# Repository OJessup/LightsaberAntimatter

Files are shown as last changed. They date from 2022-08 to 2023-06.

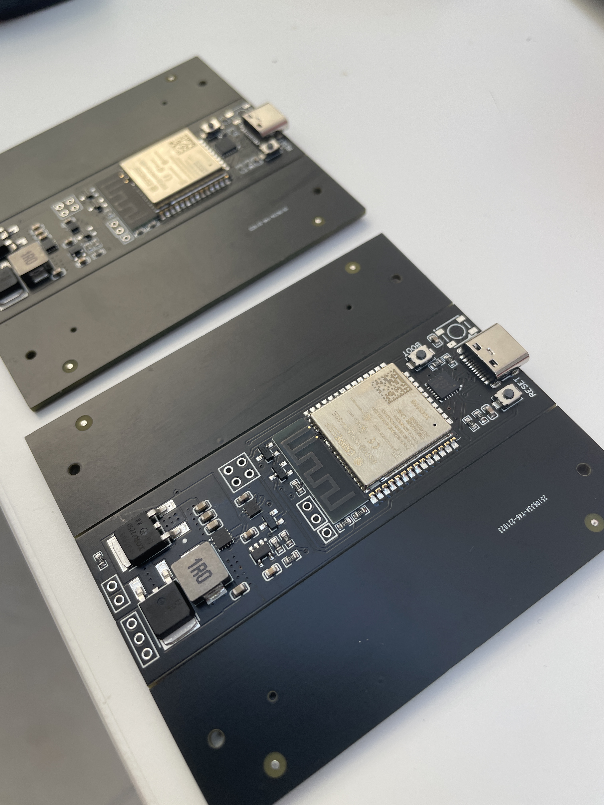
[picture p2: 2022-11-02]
ProgressDump/IMG_3393.JPG

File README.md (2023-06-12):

# LightsaberAntimatter

The LightsaberAntimatter is the third prototype of my special-fx lightsaber design.

The saber consists of two circuit boards, one with an esp-32 that controls leds that run the length of the blade, gathers readings from a gyroscope, manages a single cell battery, communicates with an iphone via bluetooth, and gathers readings from 4 VL53L5CX ToF sensors located on the second circuit board. These ToF sensors are used to detect if and where the lightsaber is hit along the blade, allowing the ability for the lightsaber to flash at a particular spot along the blade, bringing greater interactivity to it's environment and reducing the vfx needed in film production.

The hilt is a custom design, gathering inspiration from the starkiller lightsaber hilt.

Schematics for the PCBS are found in the schematics folder as well as the circuitboards folder and their fabrication files are found in the PCBA file. The DocsAndDiagrams folder is a simplified block diagram of the main circuit board, though it is outdated. The main code of the board and iphone are found in Code/StableSoftware. The .step files and technical drawings for the components of the lightsaber can be found in the CAD file.


IMG_4648 (1)

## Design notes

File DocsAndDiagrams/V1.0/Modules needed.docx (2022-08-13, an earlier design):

Modules needed:

- Control board
- IMU
- DC-DC boost converter
- SR-latch
- I2S CODEC
- Amplifier & speaker
- 1 cell lipo manager
- USB-C
- Main power mosfet & led power mosfet
- ESP8266
- Capacitive touch sensor
- Current sensor

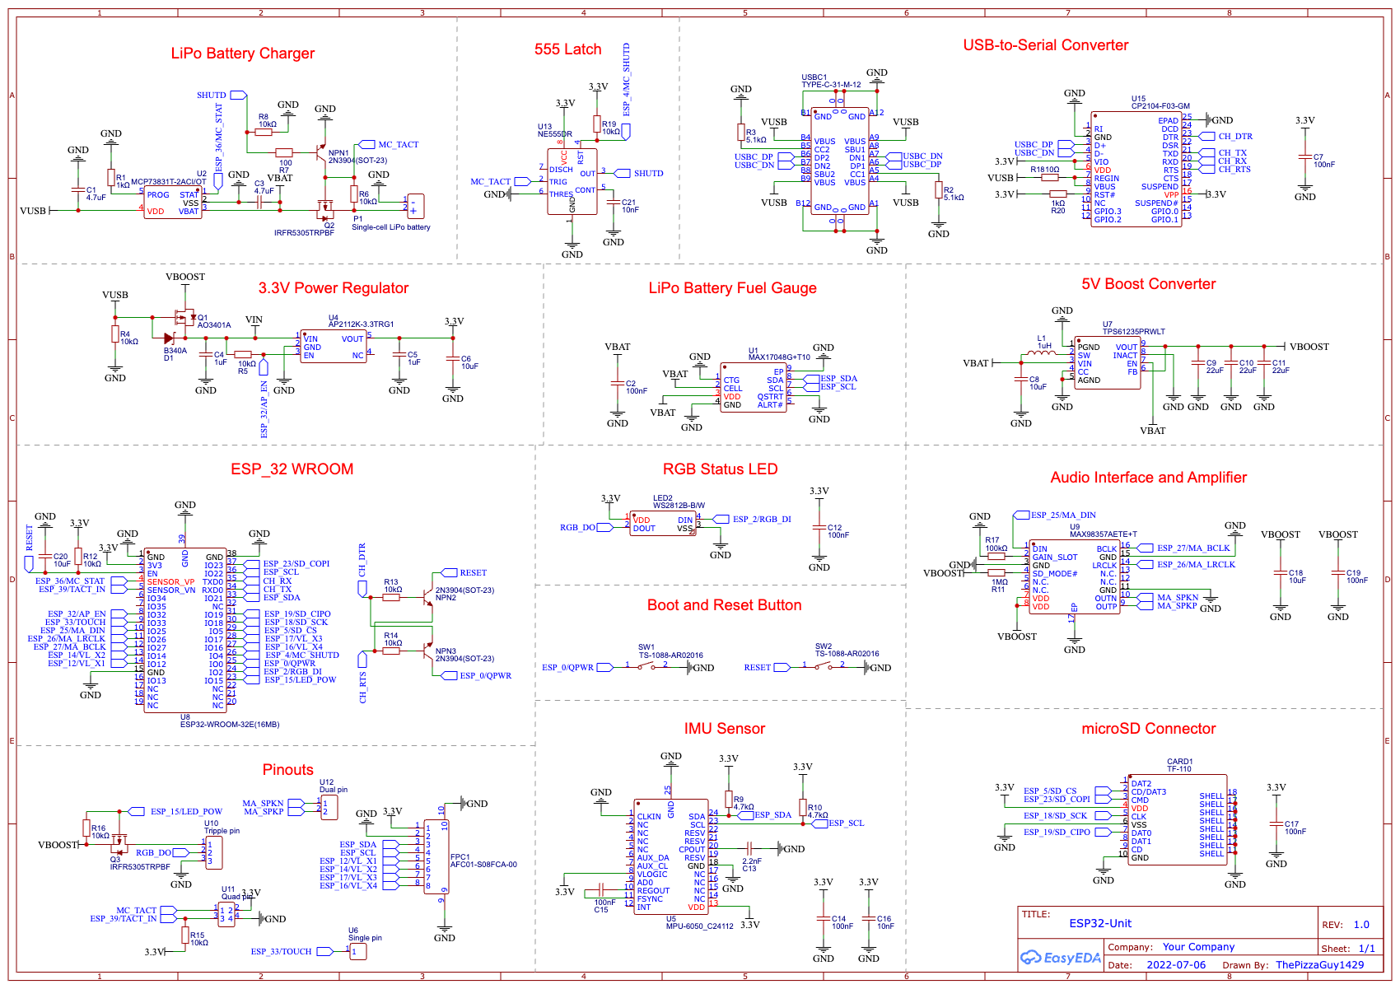
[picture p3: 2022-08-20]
Circuits/MainPCB/Schematic_Lightsaber [Anti-matter] ESP32-Unit_2022-08-20.png

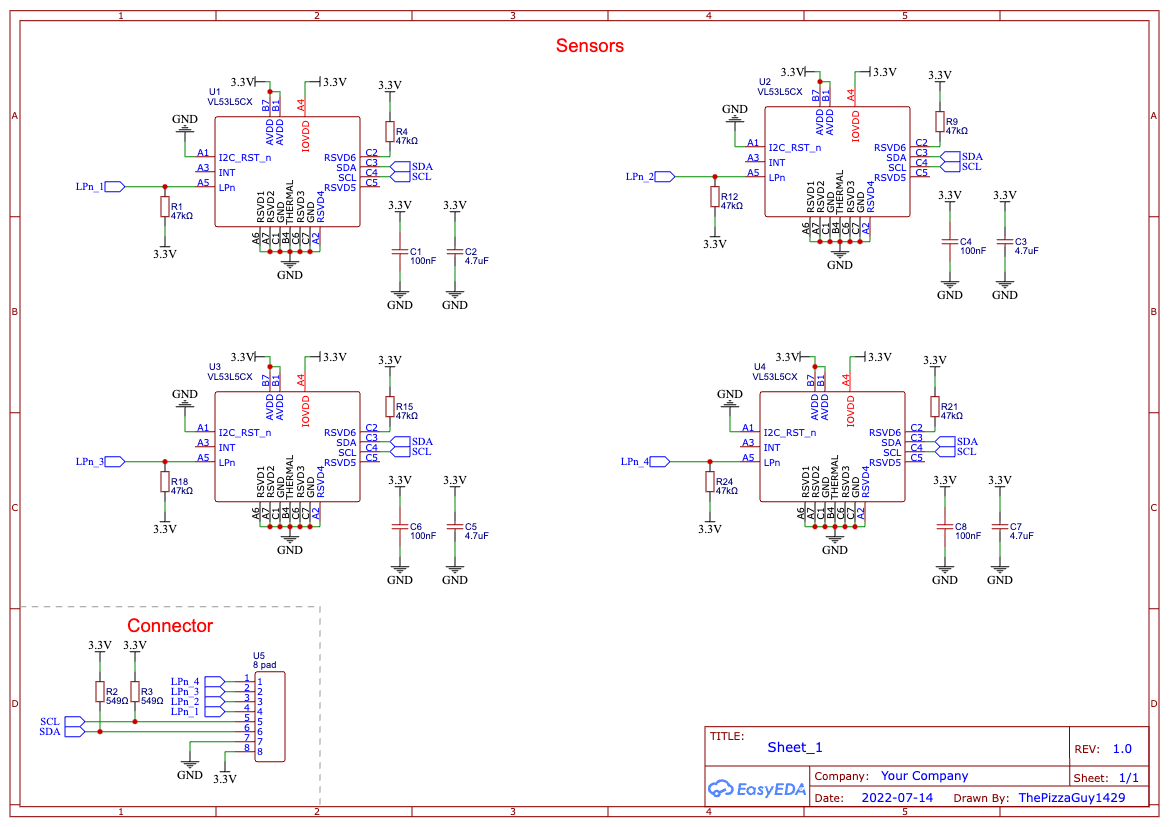
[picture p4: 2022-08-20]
Circuits/SensorPCB/Schematic_Lightsaber [Anti-matter] VL53L5CX_2022-08-20.png

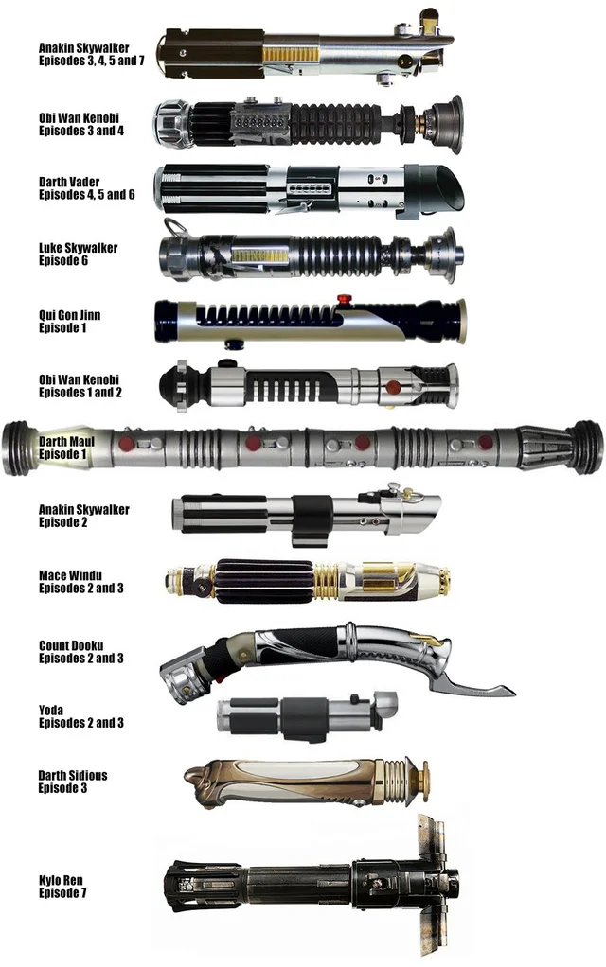
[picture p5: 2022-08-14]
Inspiration/Existing lightsabers.jpeg

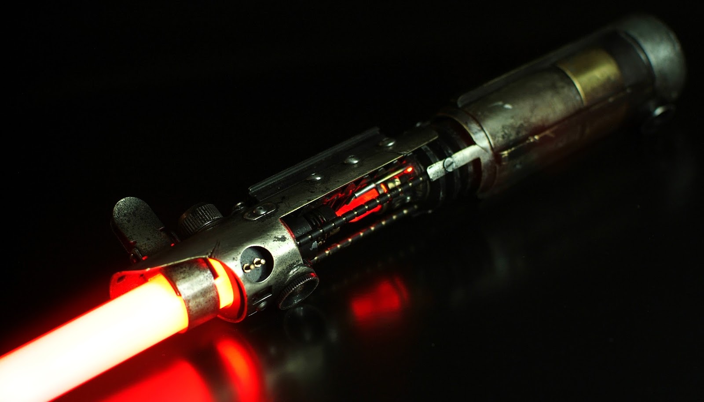
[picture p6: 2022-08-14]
Inspiration/starkiller 2.jpeg

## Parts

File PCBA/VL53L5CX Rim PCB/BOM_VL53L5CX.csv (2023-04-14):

ID | Name | Designator | Footprint | Quantity | Manufacturer Part | Manufacturer | Supplier | Supplier Part | Price
1 | 100nF | C1,C4,C6,C8 | C0603 | 4 | CC0603KRX7R9BB104 | YAGEO | LCSC | C14663
2 | 4.7uF | C2,C3,C5,C7 | C0603 | 4 | CL10A475KO8NNNC | SAMSUNG | LCSC | C19666 | 0.002
3 | 47kΩ | R1,R4,R9,R12,R15,R18,R21,R24 | R0603 | 8 | 0603WAF4702T5E | UniOhm | LCSC | C25819
4 | VL53L5CX | U1,U2,U3,U4 | VL53L5CX | 4 | VL53L5CXV0GC/1 | ST | Mouser | 511-VL53L5CXV0GC/1

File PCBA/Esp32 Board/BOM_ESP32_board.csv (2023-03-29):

ID | Name | Designator | Footprint | Quantity | Manufacturer Part | Manufacturer | Supplier | Supplier Part | Price
1 | MCP73832T-2ACI/OT | U2 | SOT-23-5_L3.0-W1.7-P0.95-LS2.8-BR | 1 | MCP73832T-2ACI/OT | MICROCHIP(美国微芯) | LCSC | C38066 | 0.149
2 | VL53L5CXMainBoard | J1 | VL53L5CXMAINBOARD | 1
3 | 100nF | C11,C1,C14,C15 | C0603 | 4 | CC0603KRX7R9BB104 | YAGEO(国巨) | LCSC | C14663
4 | 10uF | C10,C8,C21,C2 | C0603 | 4 | CL10A106MA8NRNC | SAMSUNG | LCSC | C96446 | 0.004
5 | 2.2nF | C16 | C0603 | 1 | 0603B222K500NT | FH | LCSC | C1604
6 | 100nF | C17,C18,C20 | C0603 | 3 | CC0603KRX7R9BB104 | YAGEO | LCSC | C14663
7 | 10nF | C19,C23 | C0603 | 2 | 0603B103K500NT | FH | LCSC | C57112
8 | TF-110 | CARD1 | TF-SMD_TF-110 | 1 | TF-110 | XUNPU | LCSC | C266613 | 0.038
9 | 2N3904(SOT-23) | NPN1,NPN2 | SOT-23-3_L2.9-W1.3-P1.90-LS2.4-TR | 2 | 2n3904S-RTK/PS | KEC | LCSC | C18536 | 0.002
10 | 100kΩ | R5 | R0603 | 1 | 0603WAF1003T5E | UniOhm | LCSC | C25803
11 | 1MΩ | R7 | R0603 | 1 | 0603WAF1004T5E | UniOhm | LCSC | C22935
12 | 10kΩ | R11,R12,R13,R6 | R0603 | 4 | RMC060310K1%N | Tyohm | LCSC | C269701 | 0.001
13 | MPU-6050_C24112 | U6 | QFN-24_L4.0-W4.0-P0.50-BL-EP2.7 | 1 | MPU-6050 | InvenSense | LCSC | C24112 | 1.409
14 | PCA9536D_C129522 | U7 | SOIC-8_L4.9-W3.9-P1.27-LS6.0-BL | 1 | PCA9536D | NXP(恩智浦) | LCSC | C129522 | 0.212
15 | MAX98357AETE+T | U9 | TQFN-16_L3.0-W3.0-P0.50-BL-EP1.5 | 1 | MAX98357AETE+T | MAXIM(美信) | LCSC | C910544 | 0.139
16 | 4.7uF | C12,C13 | C0603 | 2 | CL10A475KO8NNNC | SAMSUNG | LCSC | C19666 | 0.002
17 | 1kΩ | R10 | R0603 | 1 | 0603WAF1001T5E | UniOhm | LCSC | C21190
18 | 100uF | C4,C5,C9,C22,C27 | C1206 | 5 | GRM31CR61A107ME05L | muRata(村田) | LCSC | C312983 | 0.033
19 | 1uH | L1 | IND-SMD_L7.1-W6.5-P5.60 | 1 | SPM6530T-1R0M120 | TDK | LCSC | C87572 | 0.03
20 | 5V | J4 | HDR-M-2.54_1X2 | 1 |  |  | LCSC | C124375 | 0.004
21 | LEDout | J7 | HDR-M-2.54_1X1 | 1 |  |  | LCSC | C81276 | 0.001
22 | TS-1088-AR02016 | BOOT,RST | SW-SMD_L4.0-W2.9-LS5.0 | 2 | TS-1088-AR02016 | XUNPU | LCSC | C720477 | 0.008
23 | 22uF | C3 | C0603 | 1 | CL10A226MQ8NRNC | SAMSUNG(三星) | LCSC | C59461 | 0.001
24 | 10pF | C25 | C0603 | 1 | CL10C100JB8NNNC | SAMSUNG(三星) | LCSC | C1634 | 0.001
25 | 1uF | C6,C7,C24,C26 | C0603 | 4 | CL10A105KB8NNNC | SAMSUNG | LCSC | C15849 | 0.001
26 | B5819WS_C169530 | D1,D2,D3 | SOD-323F_L2.0-W1.6-LS2.5-RD | 3 | B5819WS | 晶导微电子 | LCSC | C169530 | 0.003
27 | SPEAKER | J2 | HDR-M-2.54_1X2 | 1 |  |  | LCSC | C124375 | 0.004
28 | BUTTON | J6 | HDR-M-2.54_1X2 | 1 |  |  | LCSC | C124375 | 0.004
29 | TOUCH | J3 | HDR-M-2.54_1X1 | 1 |  |  | LCSC | C81276 | 0.001
30 | Lipo | J5 | HDR-M-2.54_1X4 | 1 |  |  | LCSC | C124378 | 0.007
31 | WS2812B-B/W | LED1 | LED-SMD_4P-L5.0-W5.0-TL_WS2812B-B | 1 | WS2812B-B/T | worldsemi | LCSC | C2761795 | 0.015
32 | AO3401A | Q1 | SOT-23_L2.9-W1.3-P1.90-LS2.4-BR | 1 | AO3401A | AOS | LCSC | C15127 | 0.013
33 | AO3400A | Q3 | SOT-23-3_L2.9-W1.6-P1.90-LS2.8-BR | 1 | AO3400A | AOS | LCSC | C20917 | 0.013
34 | AO4485 | Q4 | SOIC-8_L5.0-W4.0-P1.27-LS6.0-BL | 1 | AO4485 | AOS | LCSC | C51499 | 0.052
35 | 100kΩ | R1,R8,R9 | R0603 | 3 | 0603WAF1003T5E | UNI-ROYAL(厚声) | LCSC | C25803
36 | 1MΩ | R2,R15,R16 | R0603 | 3 | 0603WAF1004T5E | UNI-ROYAL(厚声) | LCSC | C22935
37 | 35.7kΩ | R14 | R0603 | 1 | RTT033572FTP | RALEC(旺诠) | LCSC | C103569
38 | 2.2kΩ | R17,R19 | R0603 | 2 | 0603WAF2201T5E | UNI-ROYAL(厚声) | LCSC | C4190
39 | 332kΩ | R18 | R0603 | 1 | 0603WAF3323T5E | UNI-ROYAL(厚声) | LCSC | C23139
40 | ESP32-WROOM-32E(16MB) | U1 | WIFI-SMD_ESP32-WROOM-32E | 1 | ESP32-WROOM-32E(16MB) | Espressif Systems | LCSC | C701343 | 0.776
41 | XC6210B332MR_C424705 | U3 | SOT-25_L3.0-W1.6-P0.95-LS2.8-BL | 1 | XC6210B332MR | Torex Semicon | LCSC | C424705 | 0.052
42 | MAX17048G+T10 | U4 | DFN-8_L2.0-W2.0-P0.50-BL-EP | 1 | MAX17048G+T10 | MAXIM(美信) | LCSC | C2682616 | 0.241
43 | TPS61236PRWLR | U8 | VQFN-9_L2.5-W2.5-P0.50-TL | 1 | TPS61236PRWLR | TI(德州仪器) | LCSC | C130295 | 0.302
44 | 5.1kΩ | R3,R4 | R0603 | 2 | 0603WAF5101T5E | UniOhm | LCSC | C23186
45 | CP2104-F03-GM | U5 | QFN-24_L4.0-W4.0-P0.50-BL-EP2.7 | 1 | CP2104-F03-GM | SILICON LABS | LCSC | C47742 | 0.299
46 | TYPEC-304-ACP16 | USB1 | USB-C-SMD_TYPE-C-16P-1 | 1 | TYPEC-304-ACP16 | XUNPU(讯普) | LCSC | C2982555 | 0.02

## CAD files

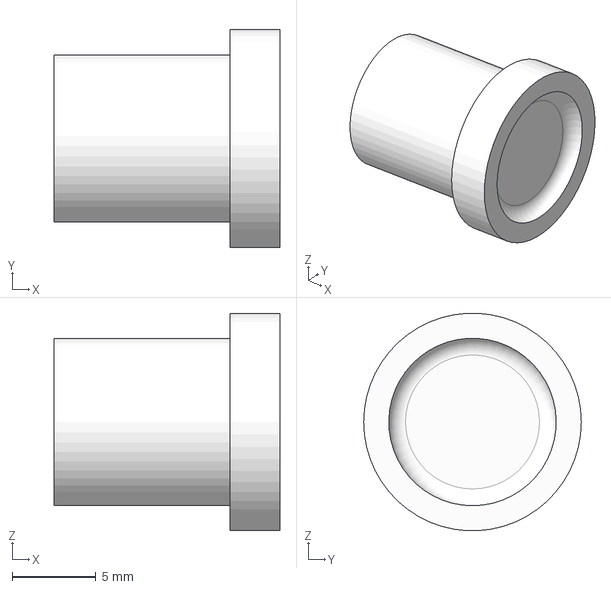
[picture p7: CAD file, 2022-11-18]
CAD/STEP files/SmallKnob-01.step
13.5 x 13.0 x 13.0 mm

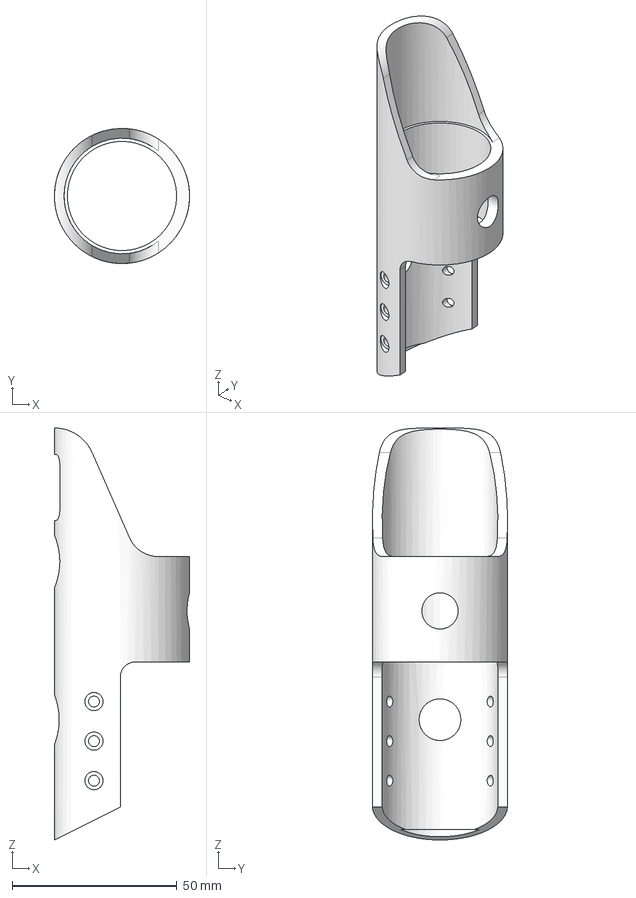
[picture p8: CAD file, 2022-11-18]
CAD/STEP files/EmitterShield-01.step
41.0 x 41.0 x 125.0 mm

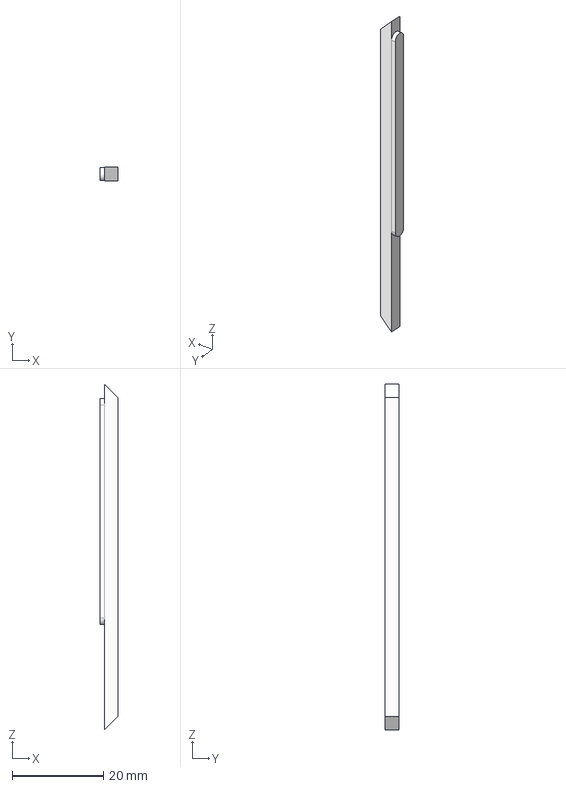
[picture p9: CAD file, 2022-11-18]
CAD/STEP files/GripRailing-01.step
4.00 x 3.00 x 76.0 mm

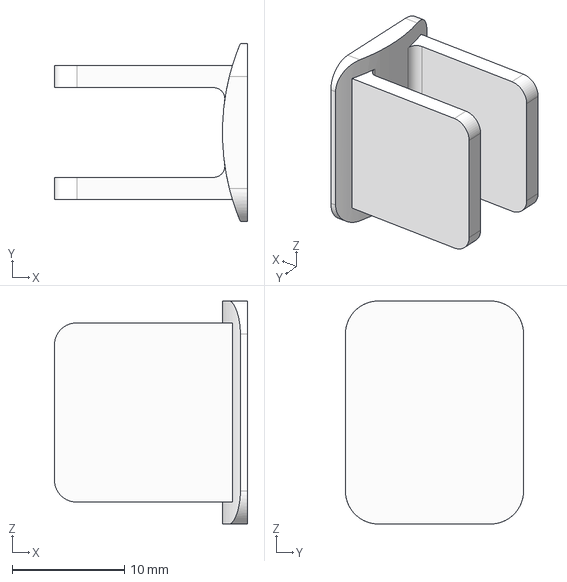
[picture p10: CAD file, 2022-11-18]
CAD/STEP files/Radiator-01.step
17.2 x 15.9 x 19.9 mm

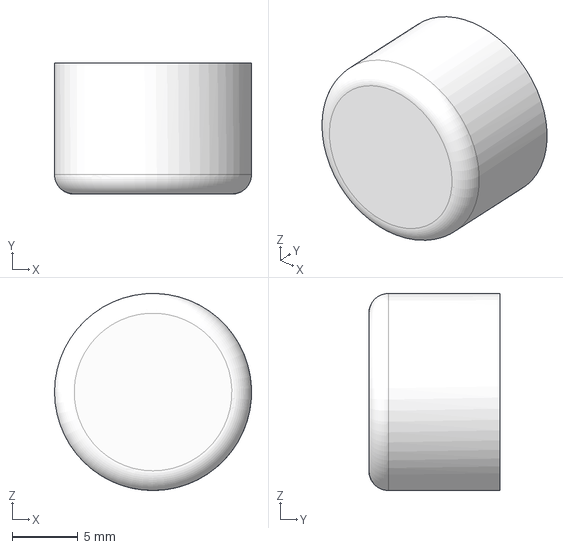
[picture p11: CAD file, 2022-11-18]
CAD/STEP files/LargeKnob-01.step
15.0 x 10.0 x 15.0 mm

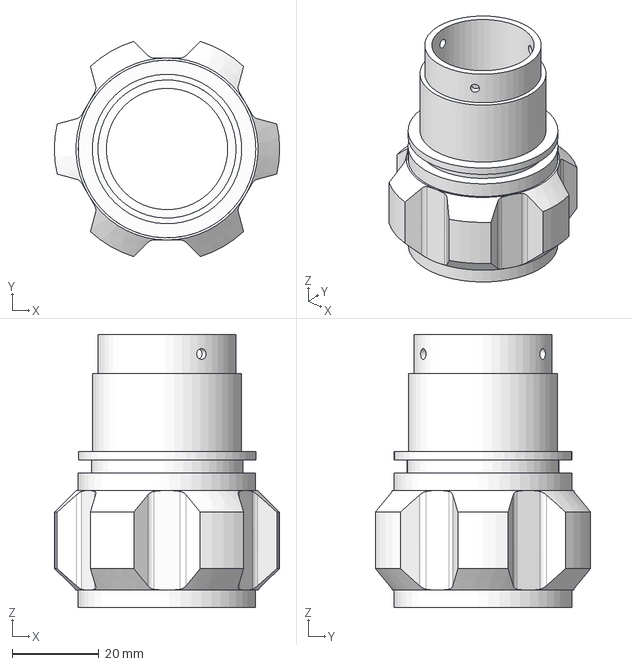
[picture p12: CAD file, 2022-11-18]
CAD/STEP files/GripButt-01.step
52.0 x 49.7 x 63.0 mm

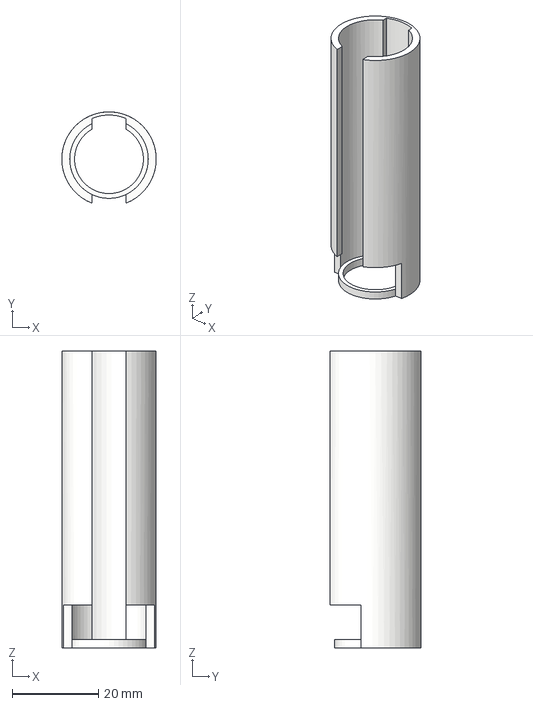
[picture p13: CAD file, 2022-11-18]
CAD/STEP files/BatteryHolder-01.step
21.9 x 21.2 x 69.0 mm

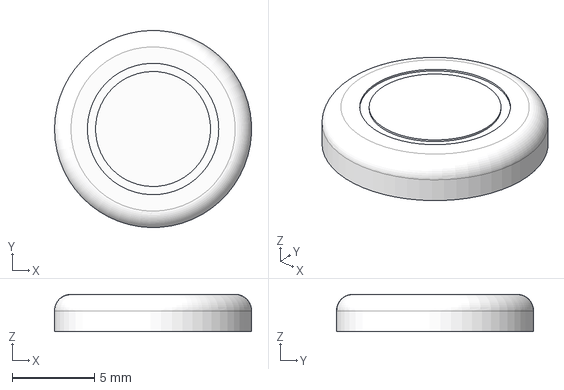
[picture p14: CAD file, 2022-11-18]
CAD/STEP files/Button-01.step
12.0 x 12.0 x 2.27 mm

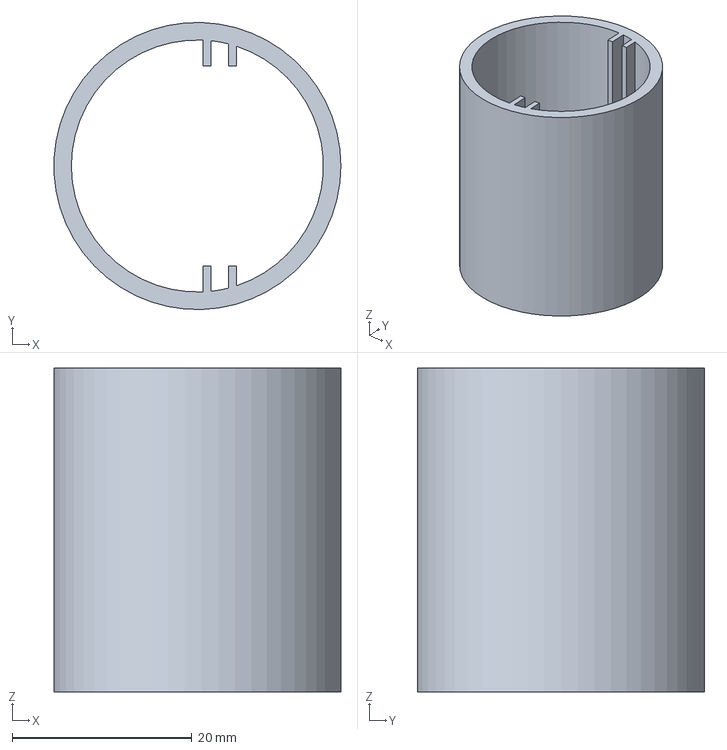
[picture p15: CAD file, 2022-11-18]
CAD/STEP files/PCBSlide-01.step
31.9 x 31.9 x 36.0 mm

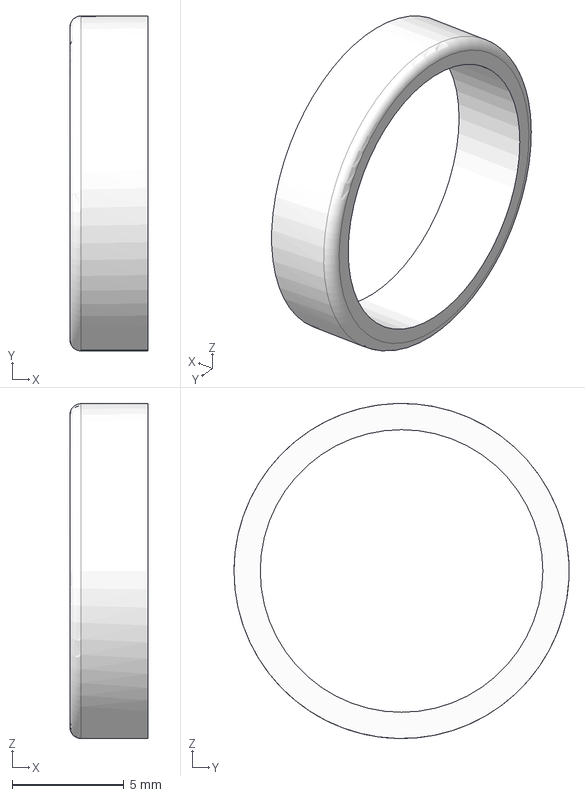
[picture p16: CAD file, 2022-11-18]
CAD/STEP files/ButtonDetail-01.step
3.50 x 15.0 x 15.0 mm

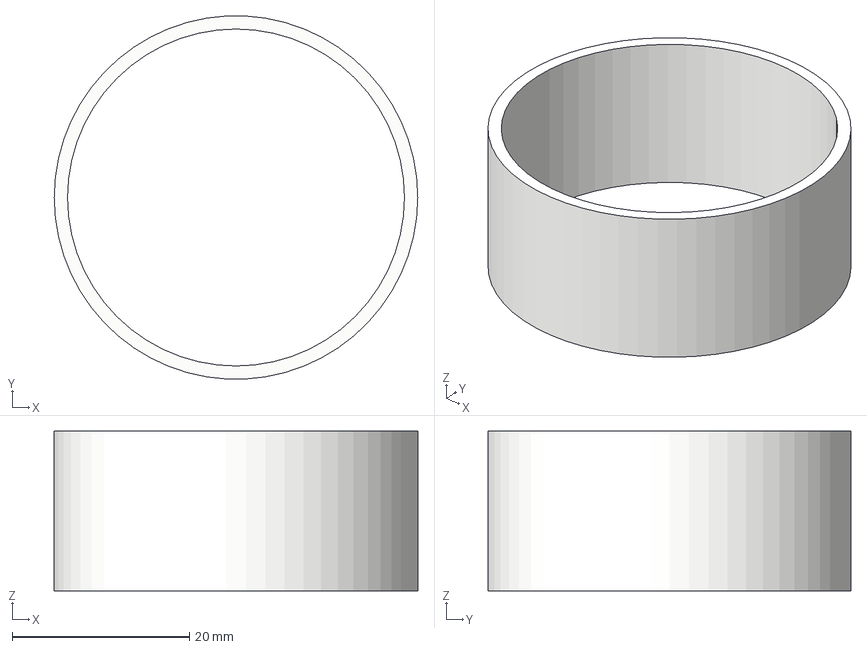
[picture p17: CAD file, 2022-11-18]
CAD/STEP files/PolycarbonateShield-01.step
41.0 x 40.9 x 18.0 mm

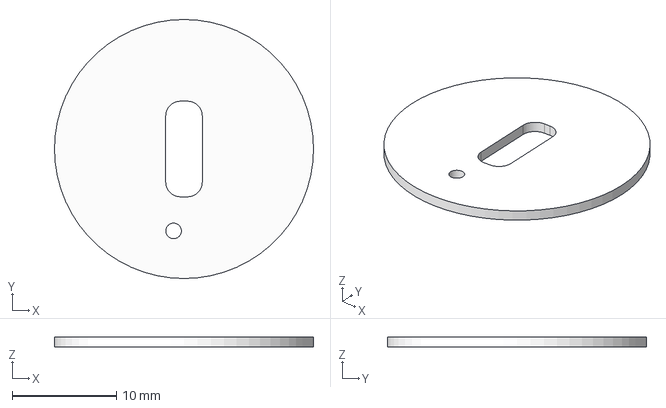
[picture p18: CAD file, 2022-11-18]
CAD/STEP files/InnerPlate-01.step
24.9 x 24.9 x 1.00 mm

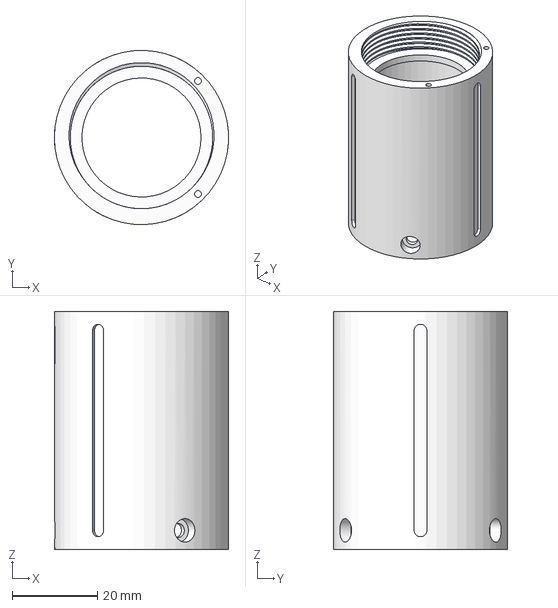
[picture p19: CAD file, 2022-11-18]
CAD/STEP files/GripShield-01.step
41.0 x 41.0 x 56.0 mm

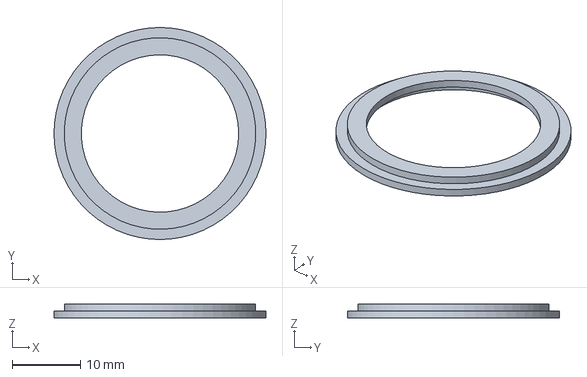
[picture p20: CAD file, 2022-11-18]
CAD/STEP files/OuterRim-01.step
31.0 x 31.0 x 2.00 mm

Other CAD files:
CAD/STEP files/Underframe-01.step
CAD/STEP files/EmitterCover-01.step

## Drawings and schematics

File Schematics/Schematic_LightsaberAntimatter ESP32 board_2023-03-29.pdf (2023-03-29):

Power Latch | 5V Step Up | USB

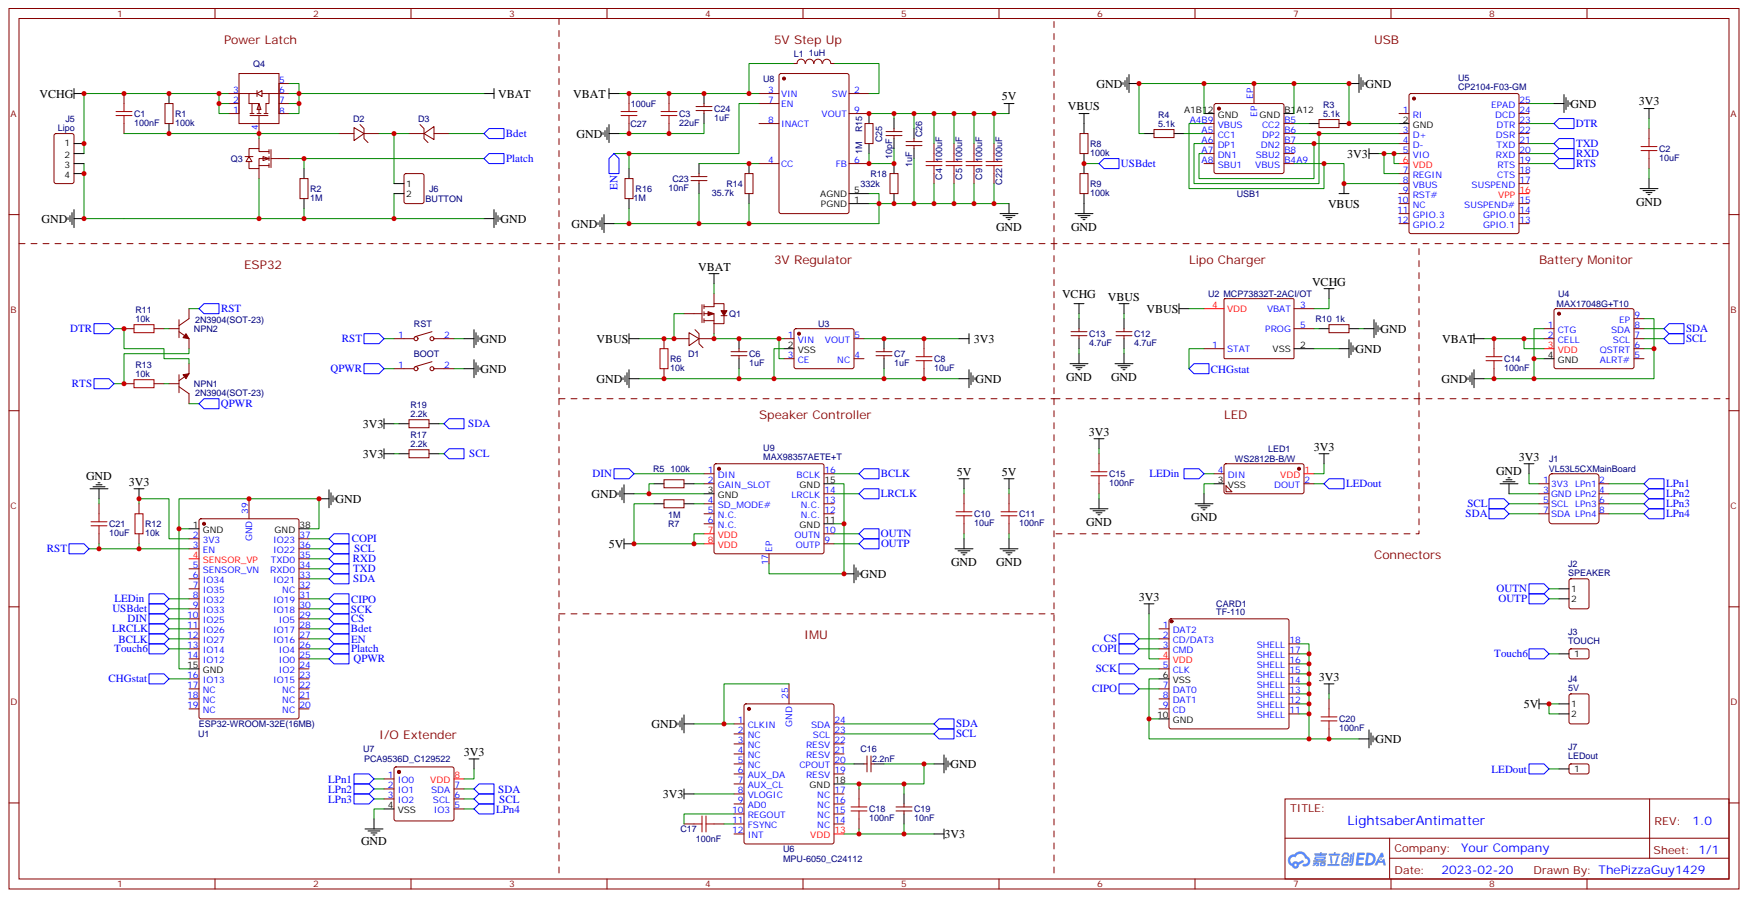
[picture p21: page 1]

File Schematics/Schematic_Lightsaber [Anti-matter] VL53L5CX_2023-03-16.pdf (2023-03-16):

# Sensors

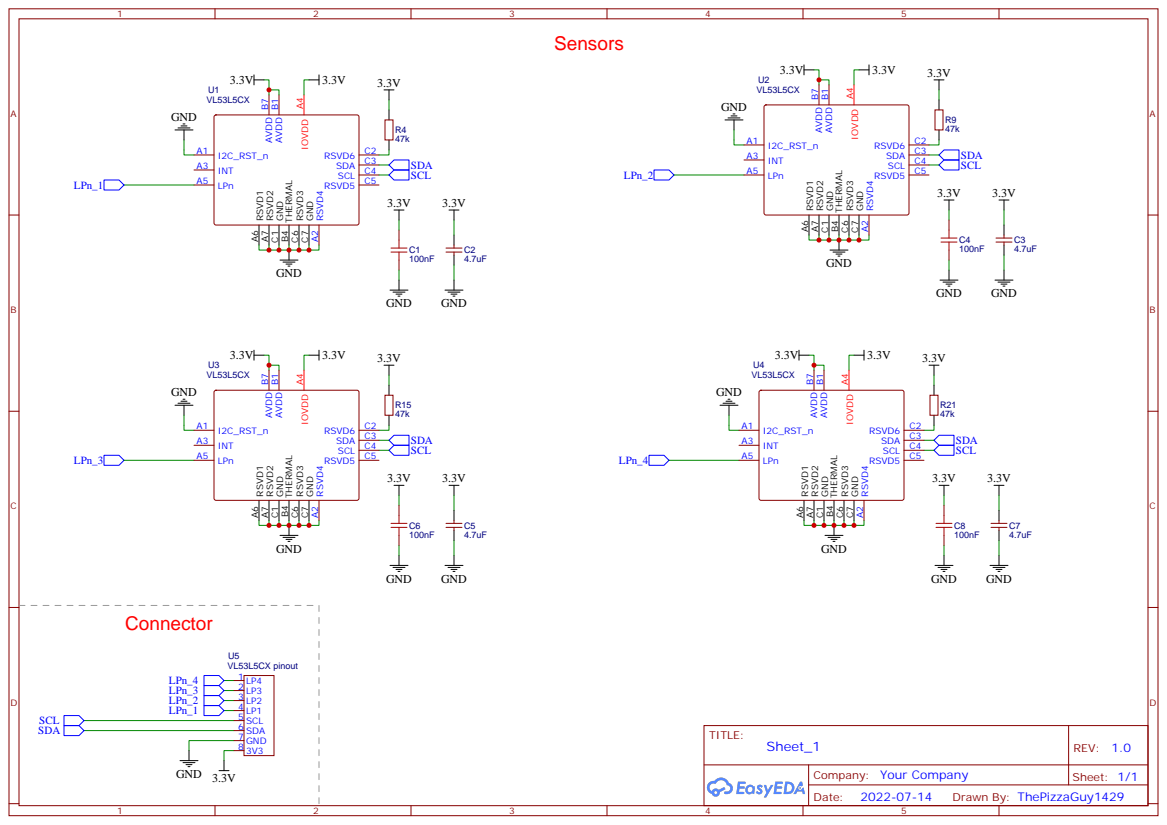
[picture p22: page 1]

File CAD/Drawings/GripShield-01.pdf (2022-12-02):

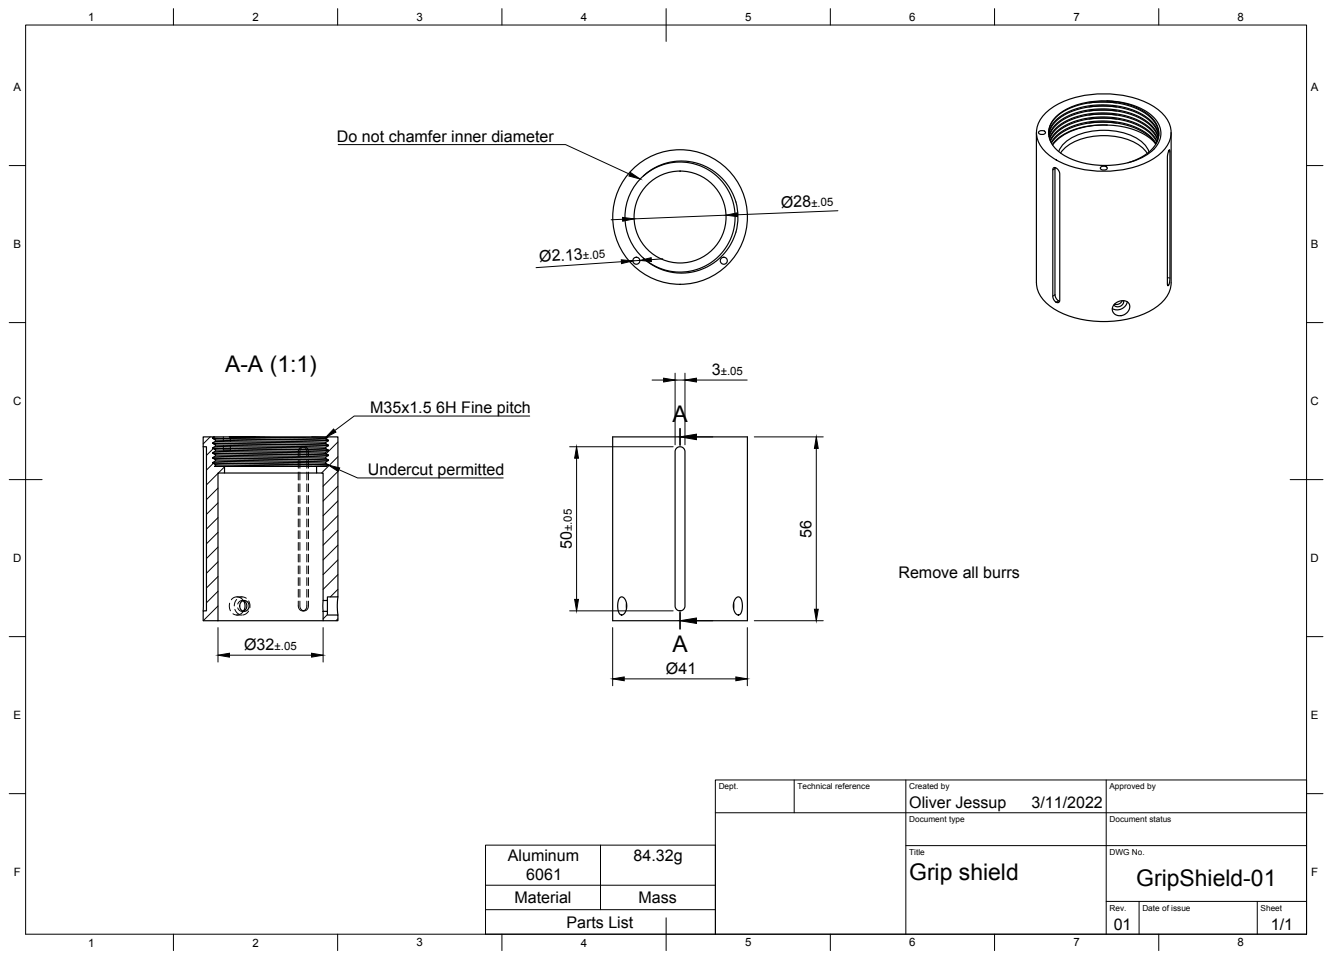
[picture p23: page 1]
Title; DWG No.; Rev.; Date of issue; Sheet; Grip shield; GripShield-01; M35x1.5 6H Fine pitch; Undercut permitted; Parts List

Do not chamfer inner diameter

Remove all burrs

Dept. | Technical reference | Created by Oliver Jessup 3/11/2022 | Approved by

Document type | Document status

Aluminum 6061 | 84.32g

Material | Mass

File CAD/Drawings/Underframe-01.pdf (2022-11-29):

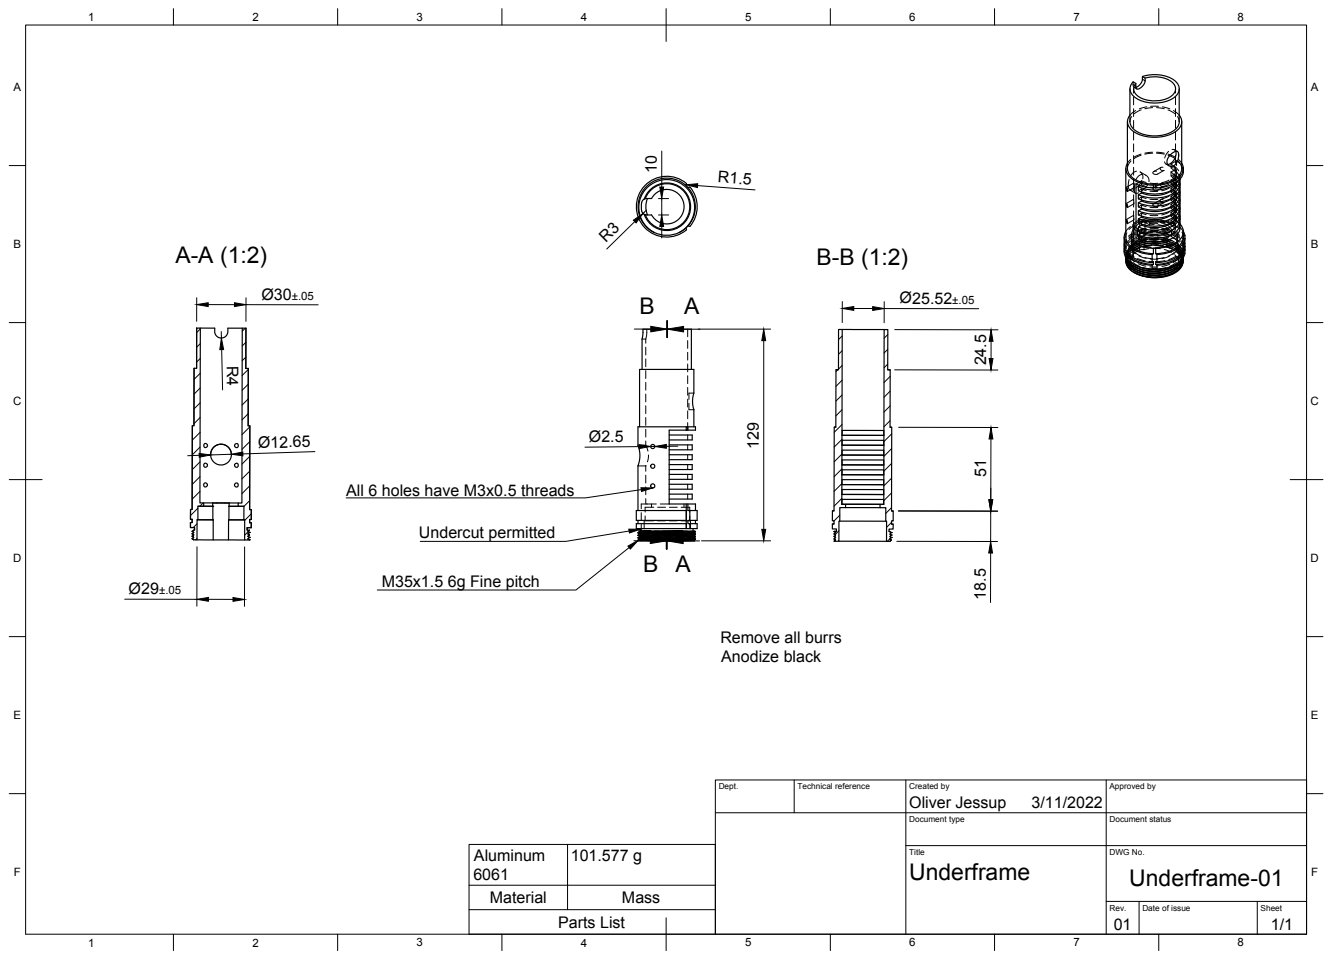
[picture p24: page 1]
Title; DWG No.; Rev.; Date of issue; Sheet; M35x1.5 6g Fine pitch; Undercut permitted; Remove all burrs; Parts List; Anodize black

All 6 holes have M3x0.5 threads

Dept. | Technical reference | Created by Oliver Jessup 3/11/2022 | Approved by

Document type | Document status

Aluminum 6061 | 101.577 g

Material | Mass

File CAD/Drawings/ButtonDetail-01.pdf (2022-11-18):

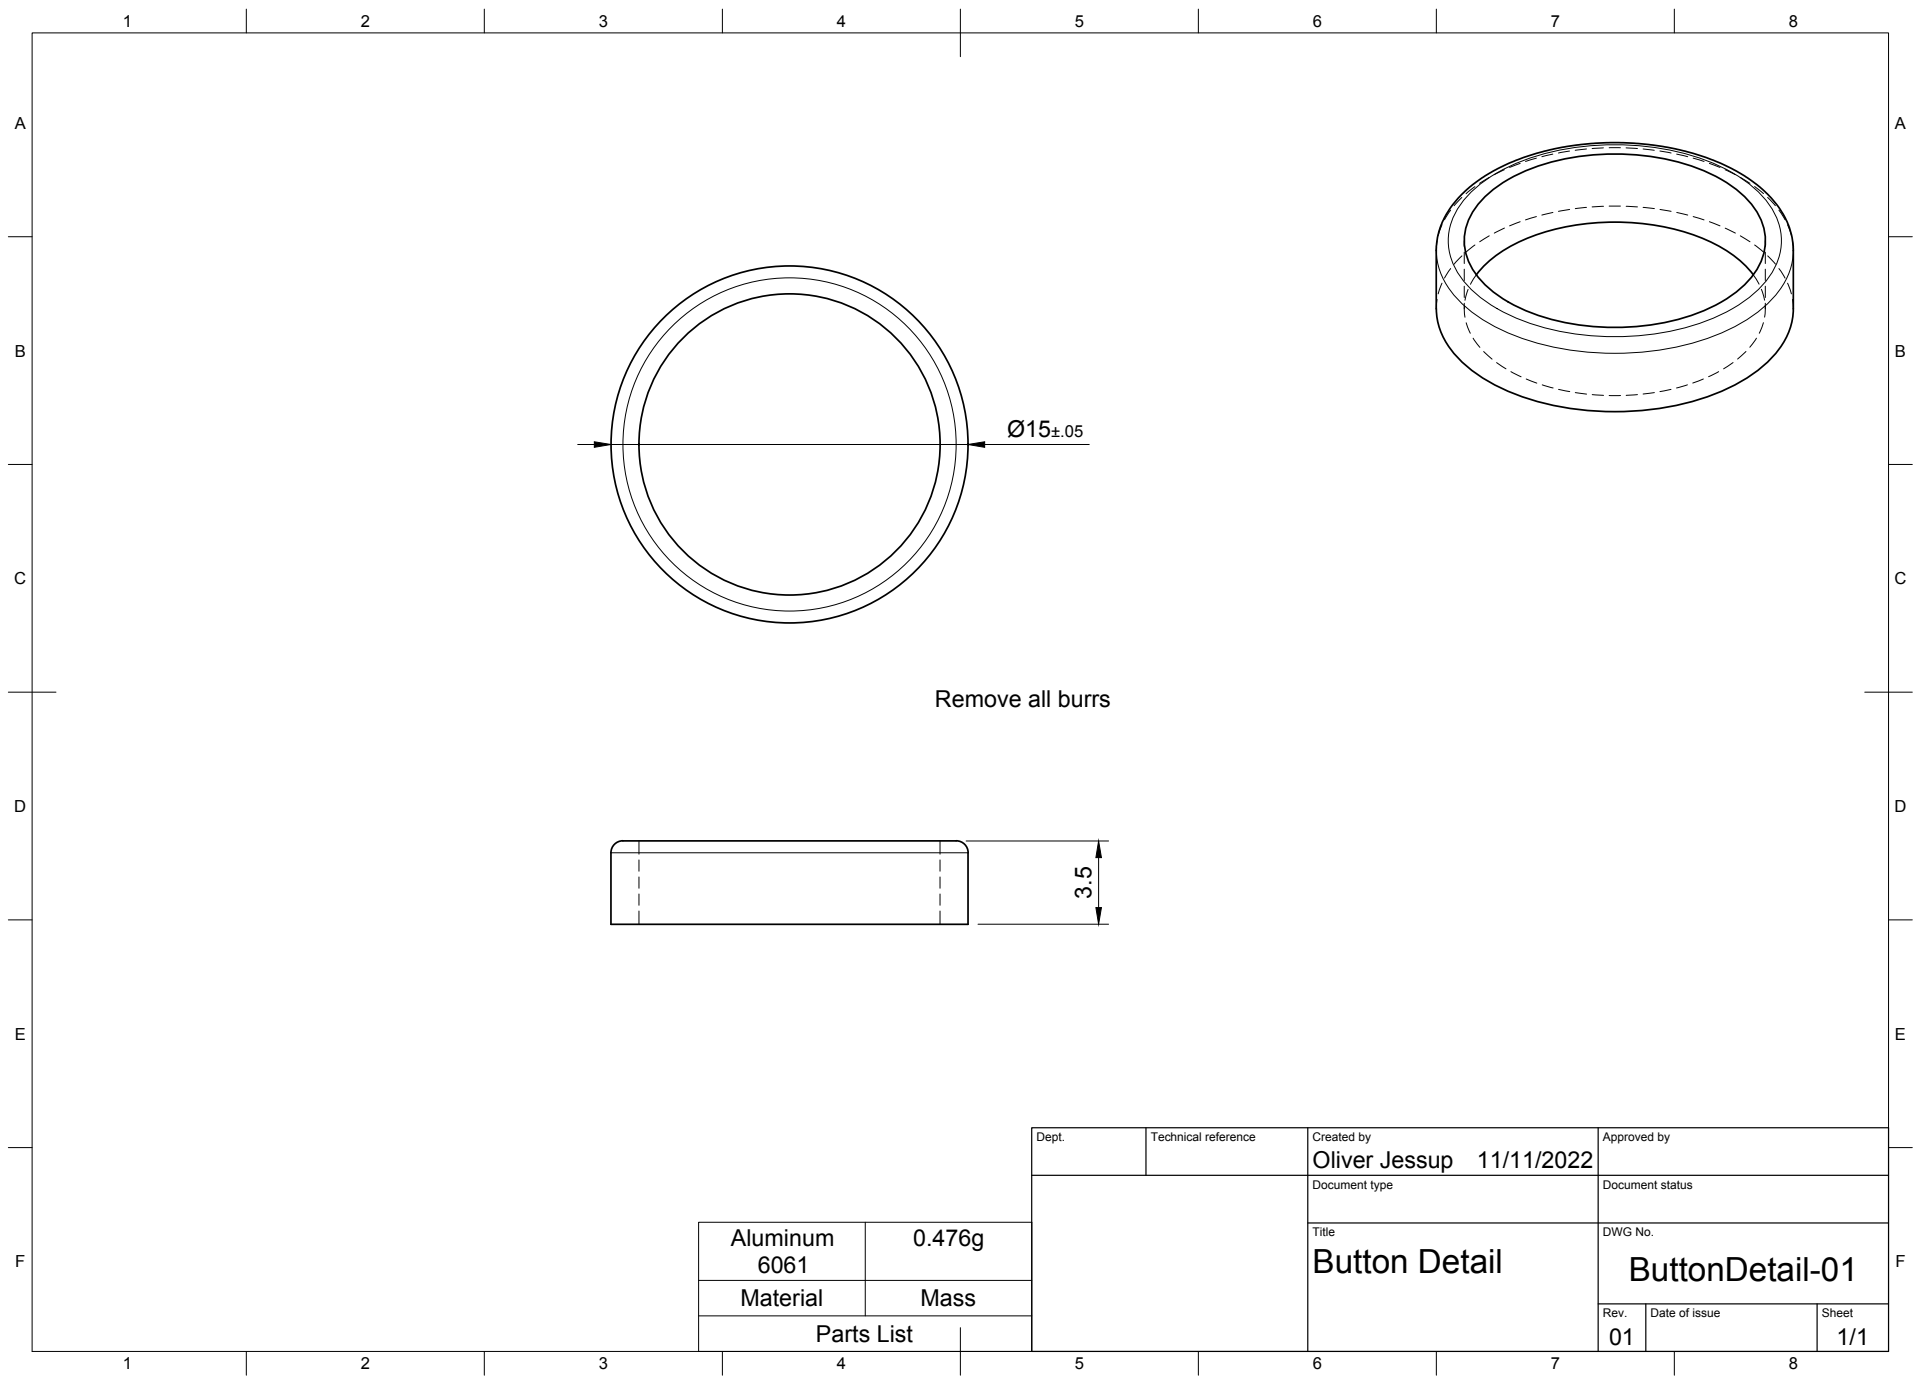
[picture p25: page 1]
Title; DWG No.; Rev.; Date of issue; Sheet; Button Detail; ButtonDetail-01; Parts List

Remove all burrs

Dept. | Technical reference | Created by Oliver Jessup 11/11/2022 | Approved by

Document type | Document status

Aluminum 6061 | 0.476g

Material | Mass

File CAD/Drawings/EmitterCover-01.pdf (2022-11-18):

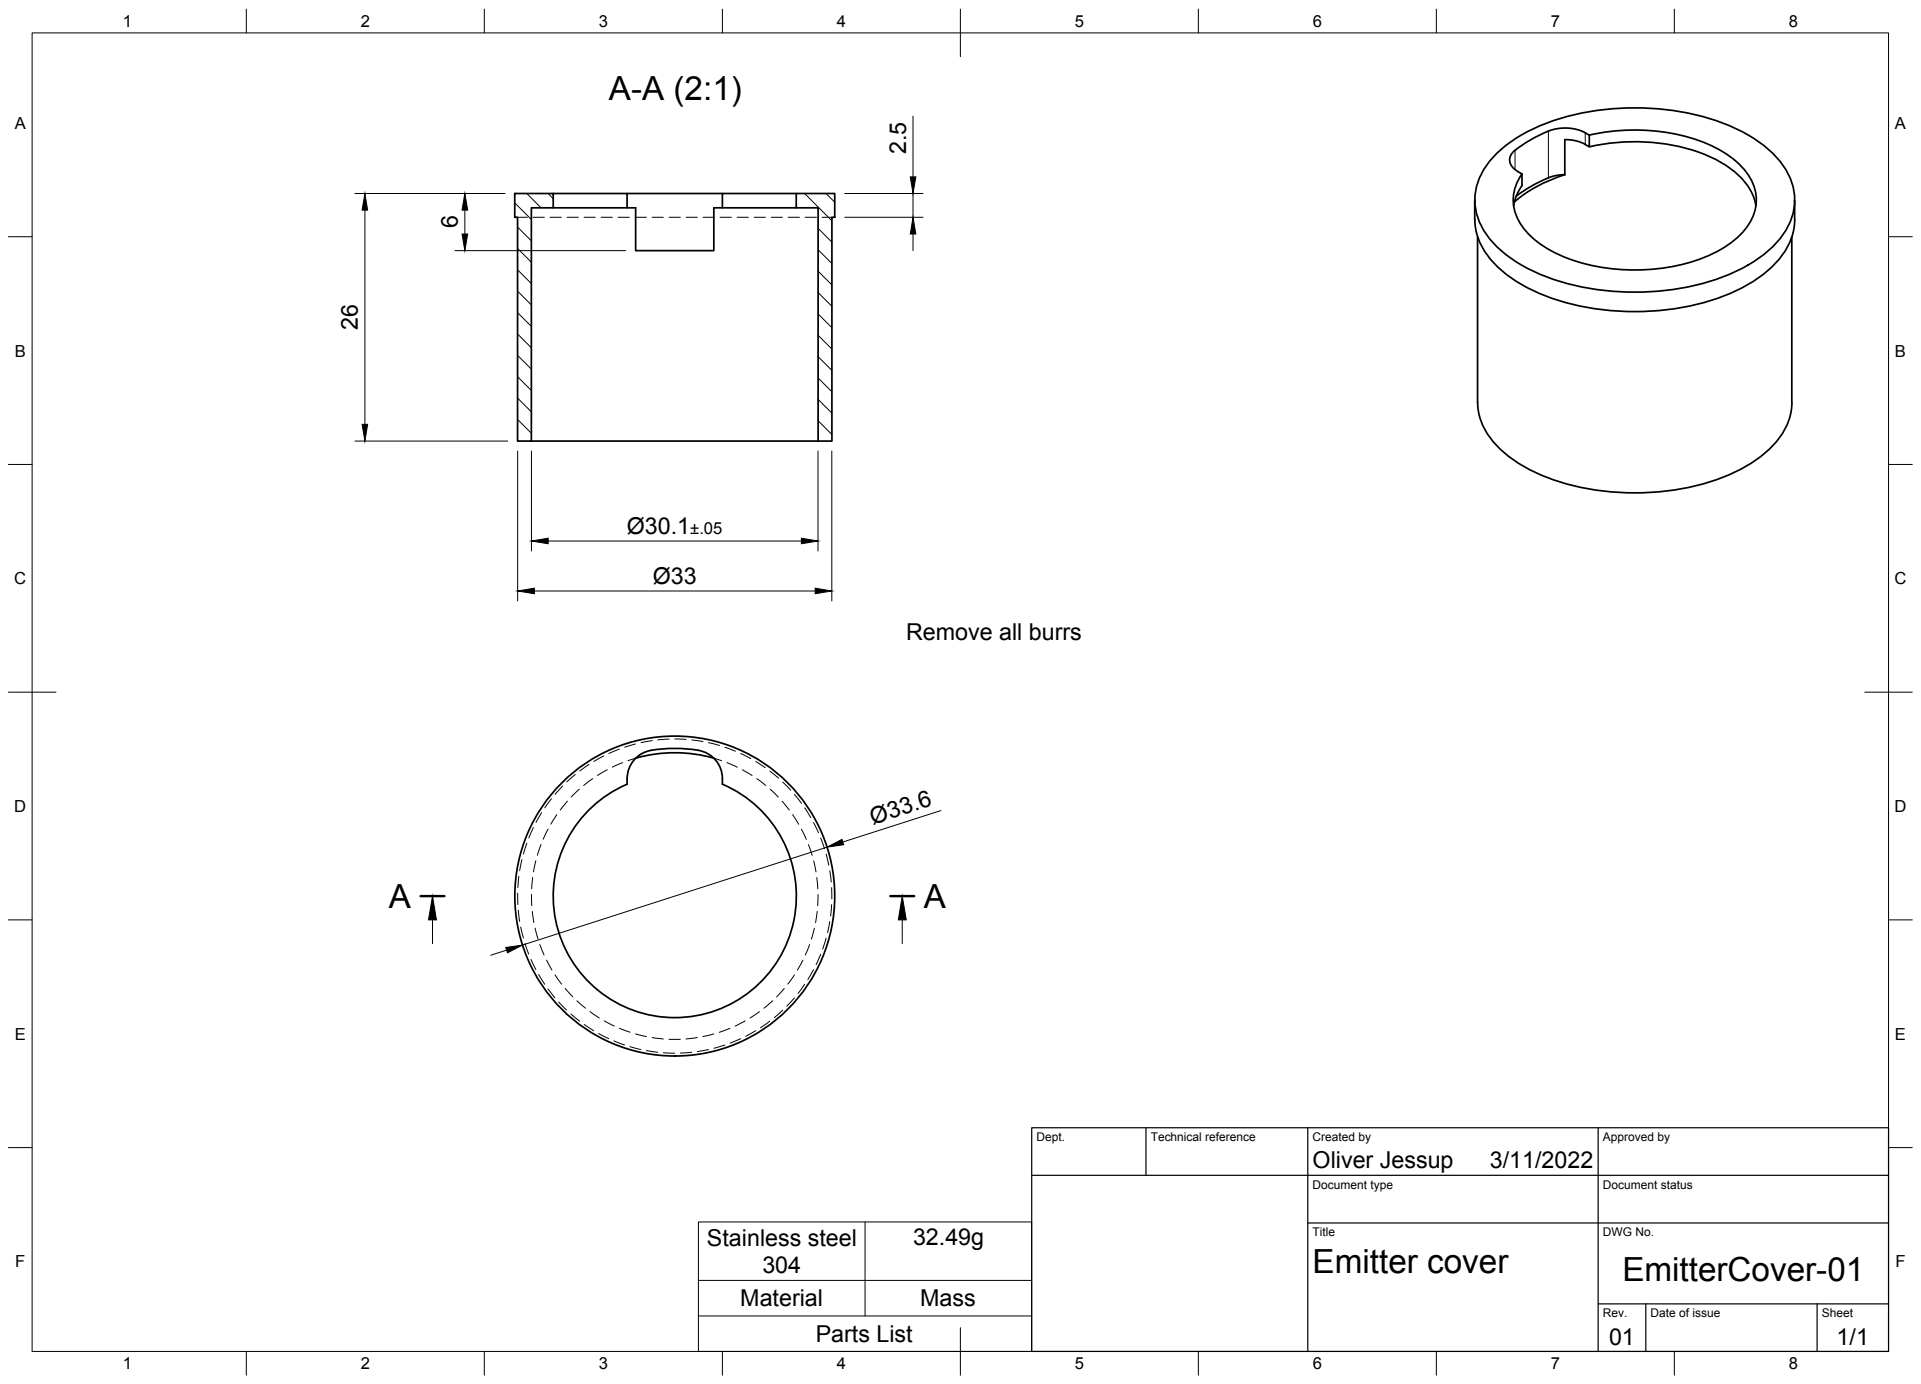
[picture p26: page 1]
Title; DWG No.; Rev.; Date of issue; Sheet; Emitter cover; EmitterCover-01; Parts List

Remove all burrs

Dept. | Technical reference | Created by Oliver Jessup 3/11/2022 | Approved by

Document type | Document status

Stainless steel 304

Material | Mass

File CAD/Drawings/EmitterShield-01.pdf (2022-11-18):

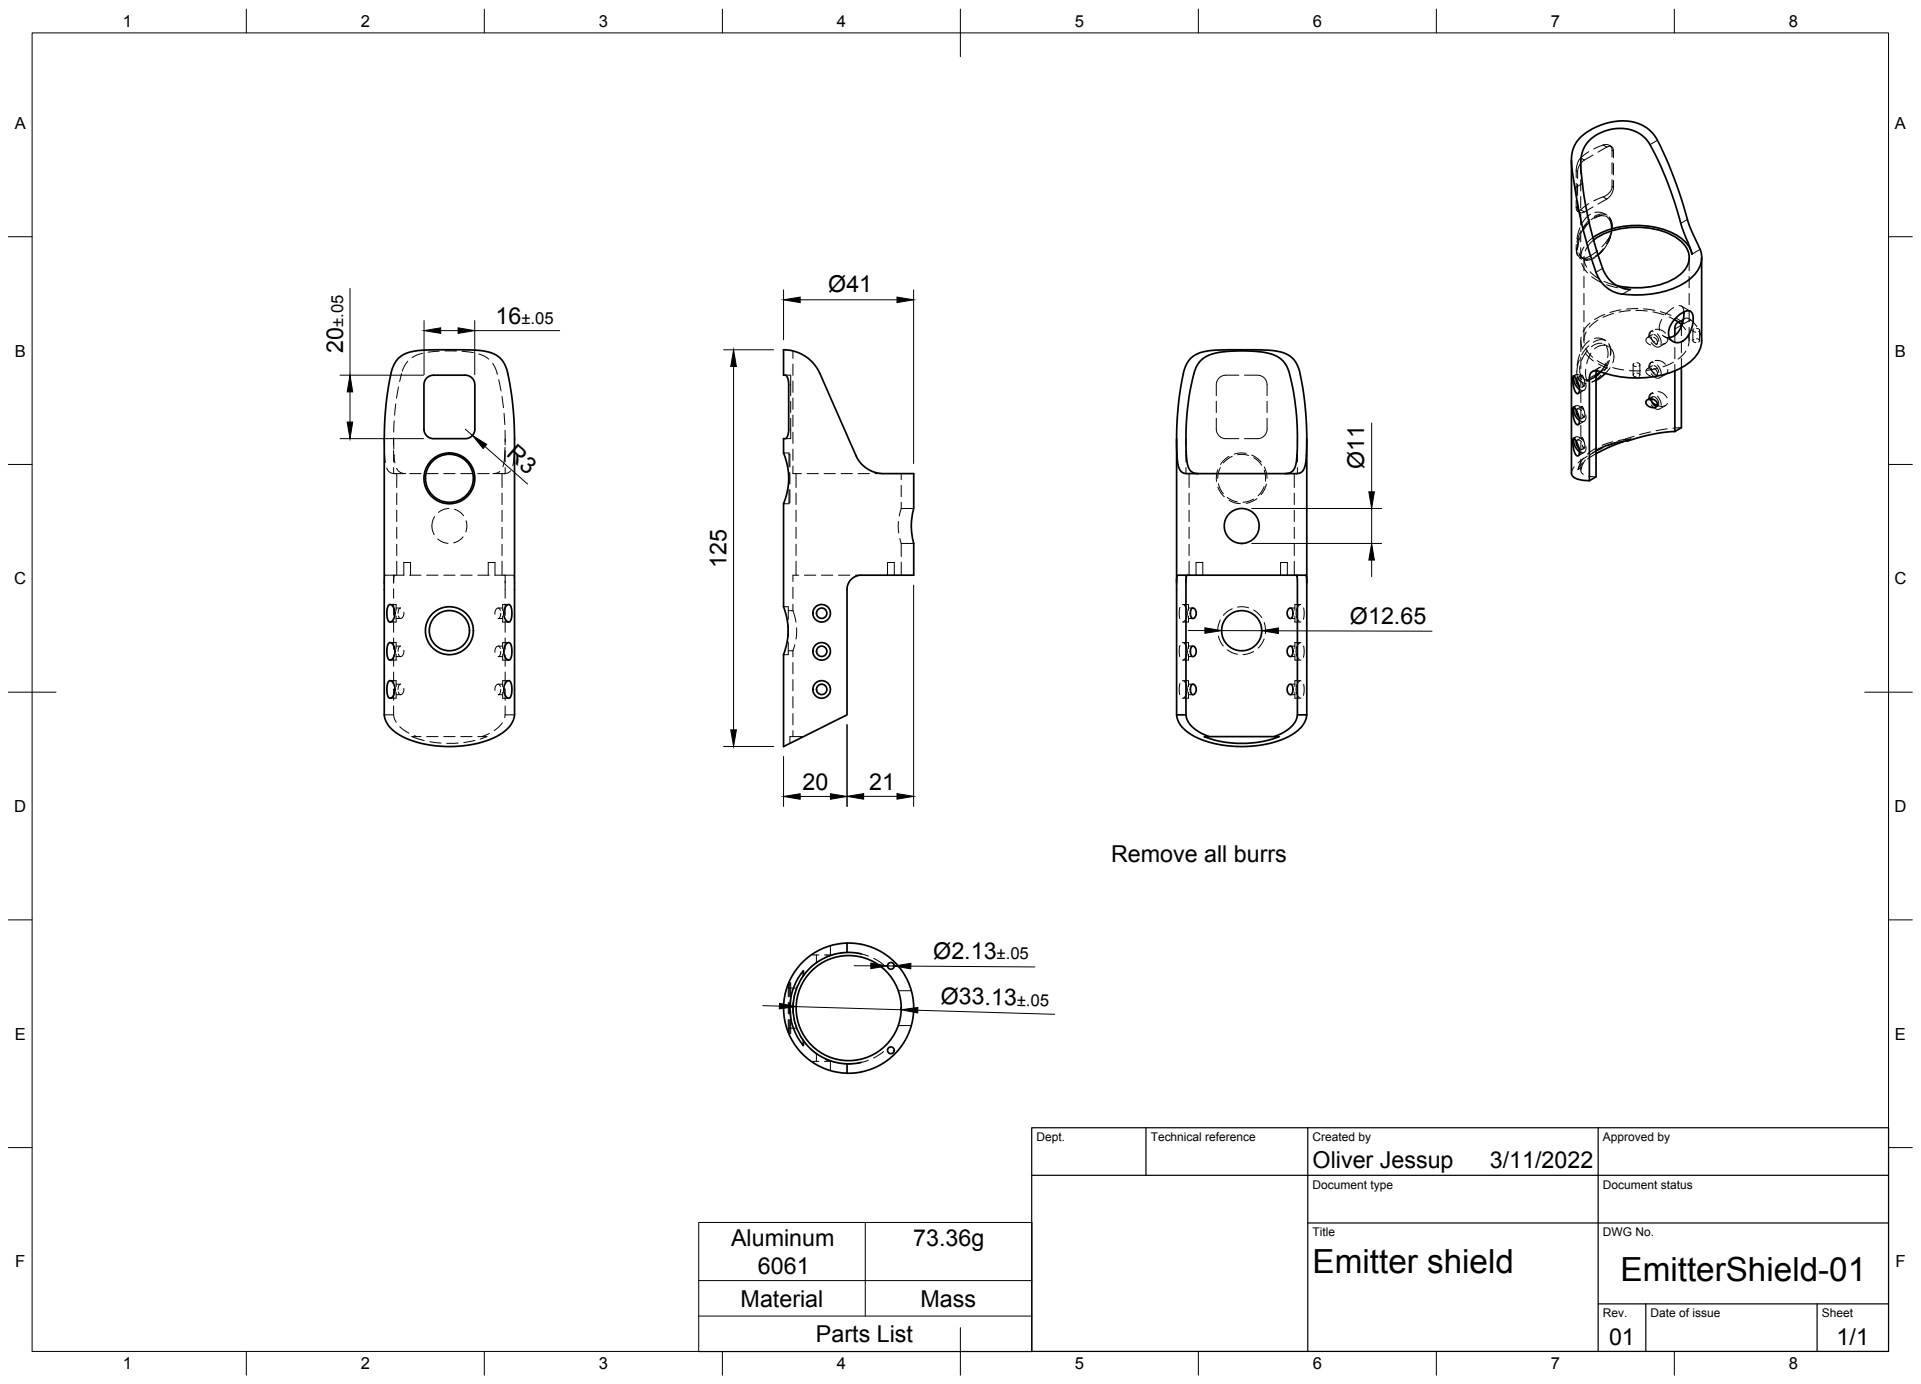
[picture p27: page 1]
Title; DWG No.; Rev.; Date of issue; Sheet; Emitter shield; EmitterShield-01; Oliver Jessup 125; Parts List

Remove all burrs

Dept. | Technical reference | Created by 3/11/2022 | Approved by

Document type | Document status

Aluminum 6061

Material | Mass

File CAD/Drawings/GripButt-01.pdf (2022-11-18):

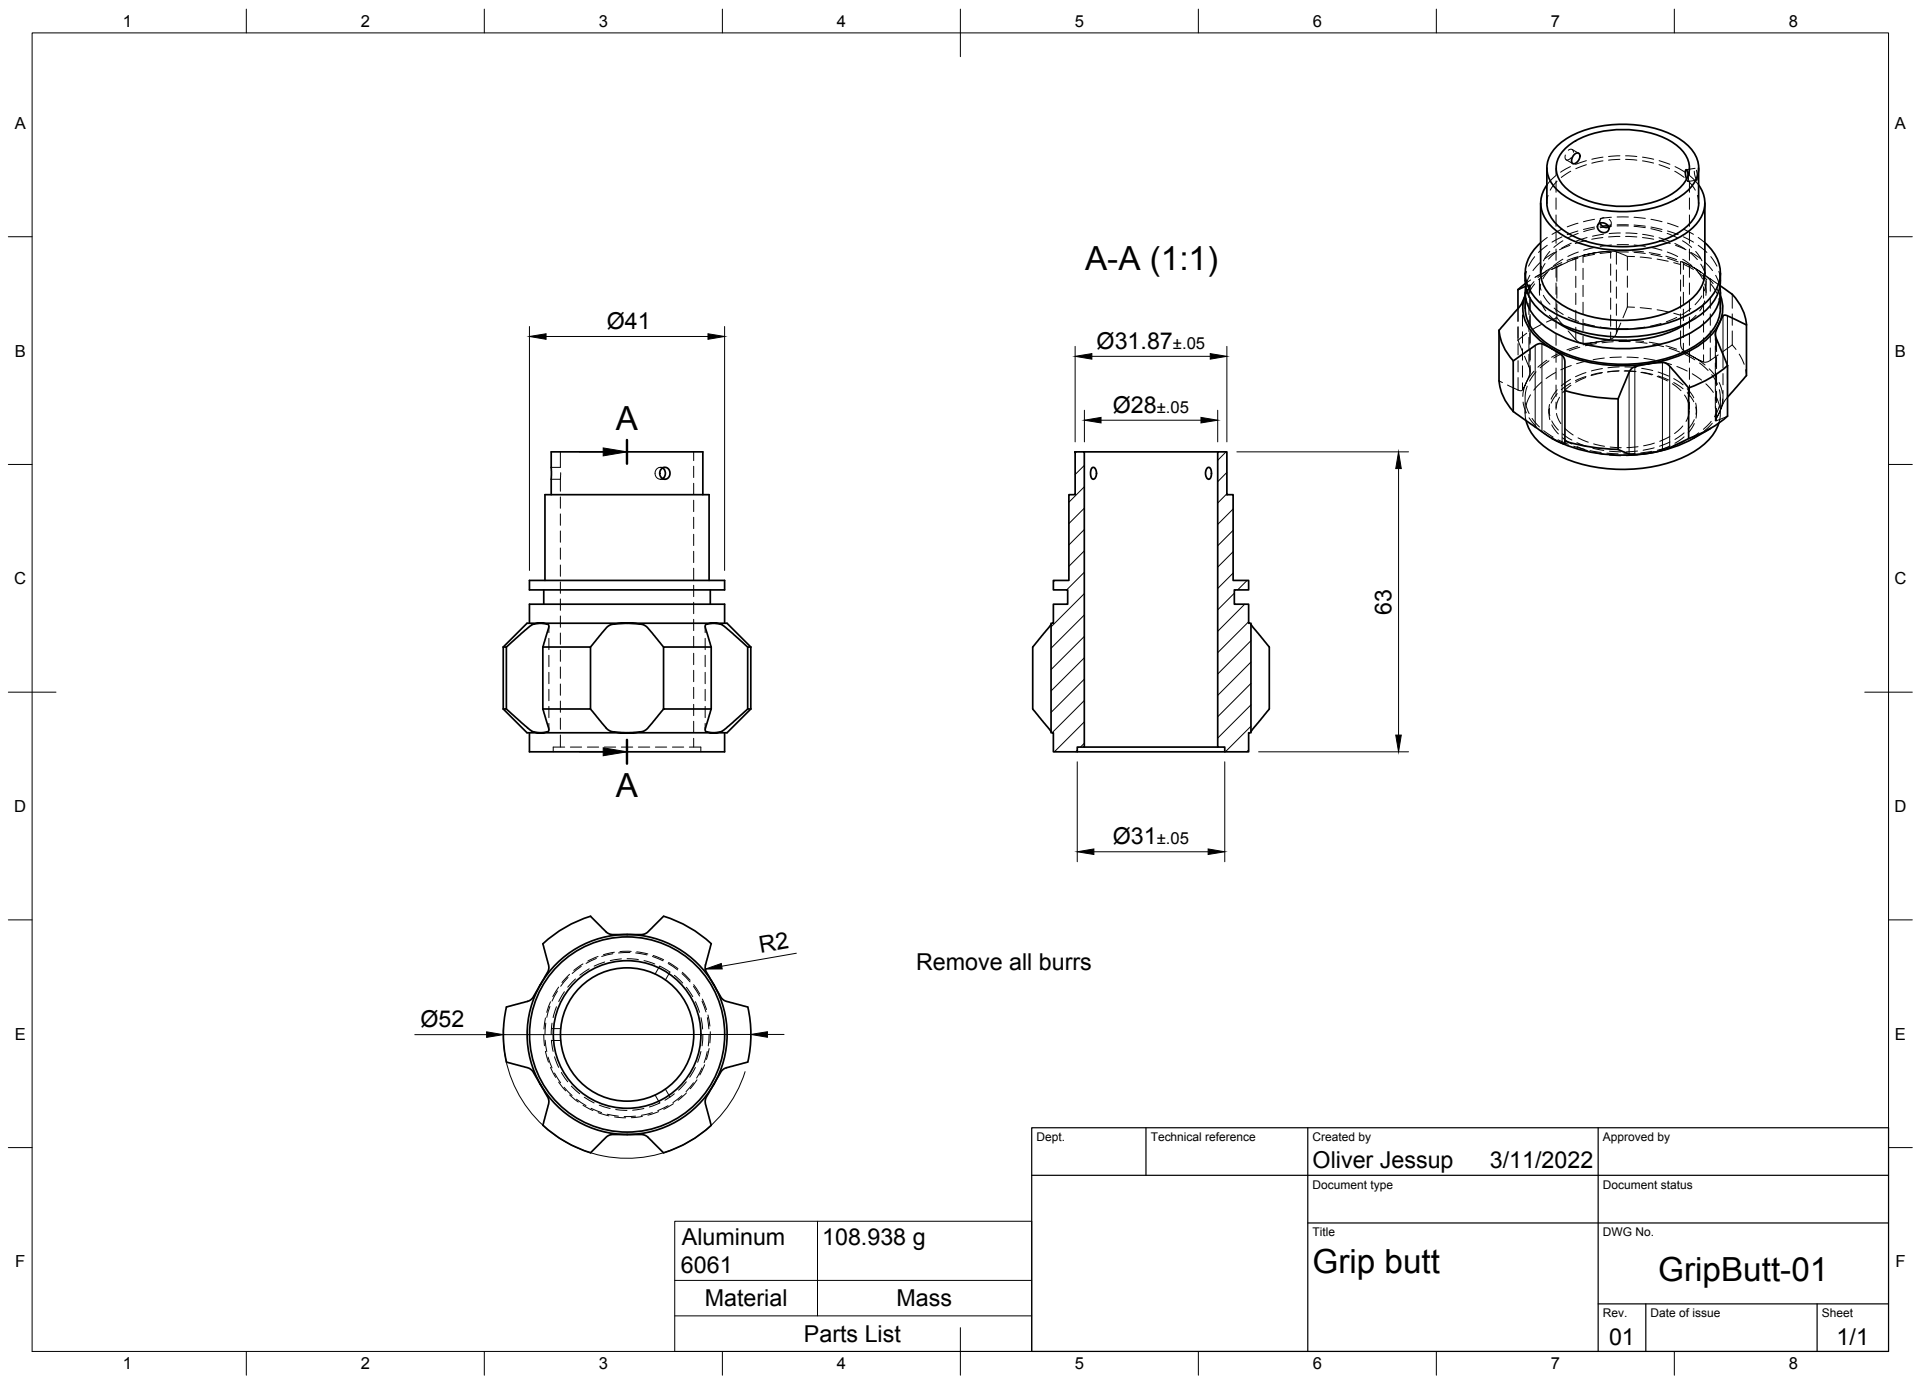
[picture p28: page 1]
Title; DWG No.; Rev.; Date of issue; Sheet; Grip butt; GripButt-01; Parts List

Remove all burrs

Dept. | Technical reference | Created by Oliver Jessup 3/11/2022 | Approved by

Document type | Document status

Aluminum 6061 | 108.938 g

Material | Mass

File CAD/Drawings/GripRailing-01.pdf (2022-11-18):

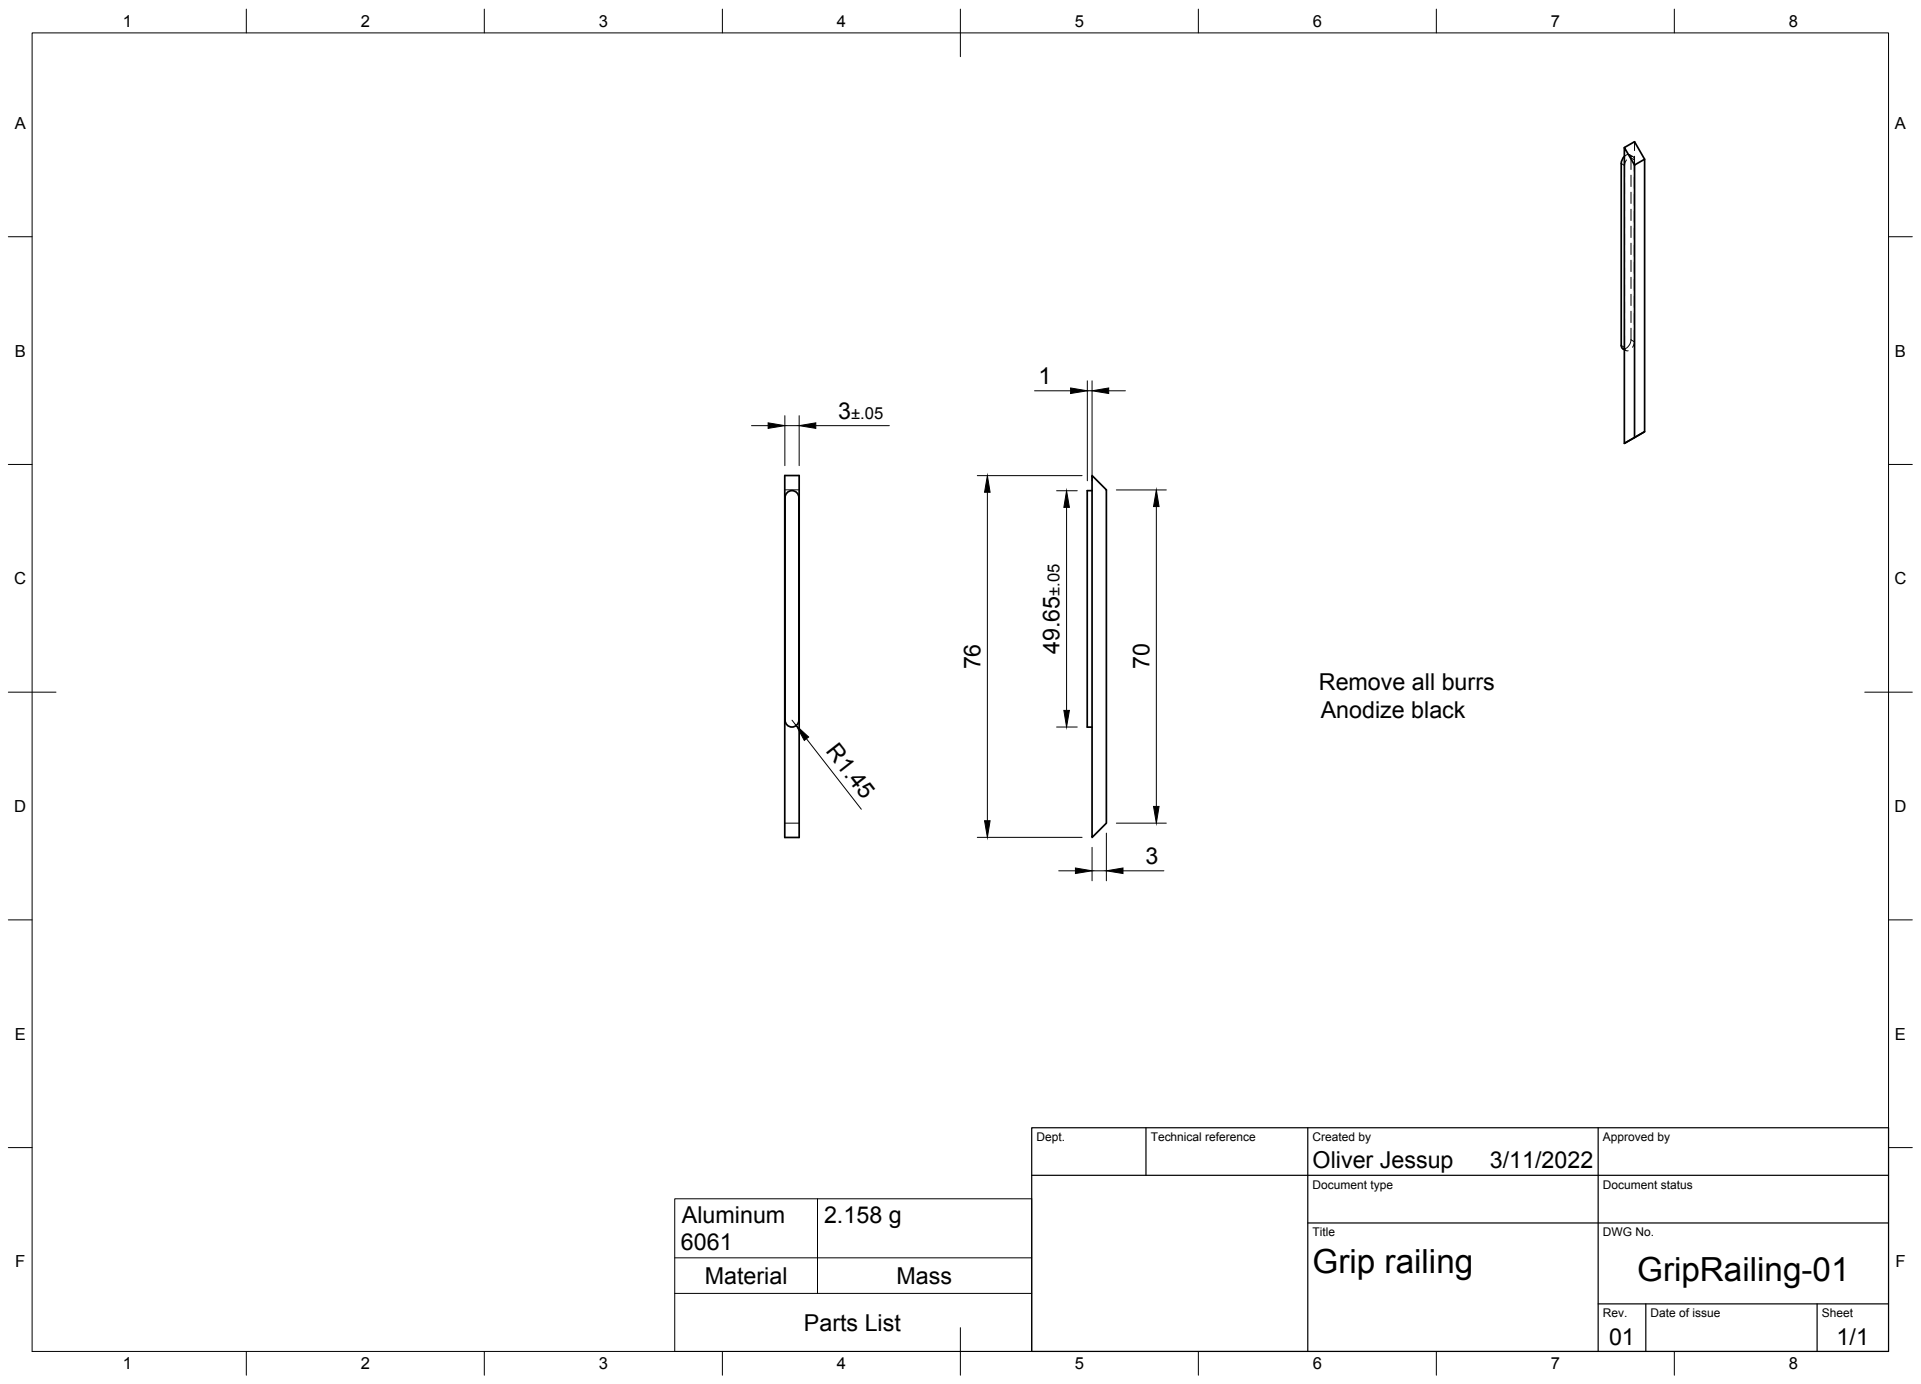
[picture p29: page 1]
Title; DWG No.; Rev.; Date of issue; Sheet; Grip railing; GripRailing-01; Parts List

Remove all burrs
Anodize black

Dept. | Technical reference | Created by Oliver Jessup 3/11/2022 | Approved by

Document type | Document status

Aluminum 6061

Material | Mass

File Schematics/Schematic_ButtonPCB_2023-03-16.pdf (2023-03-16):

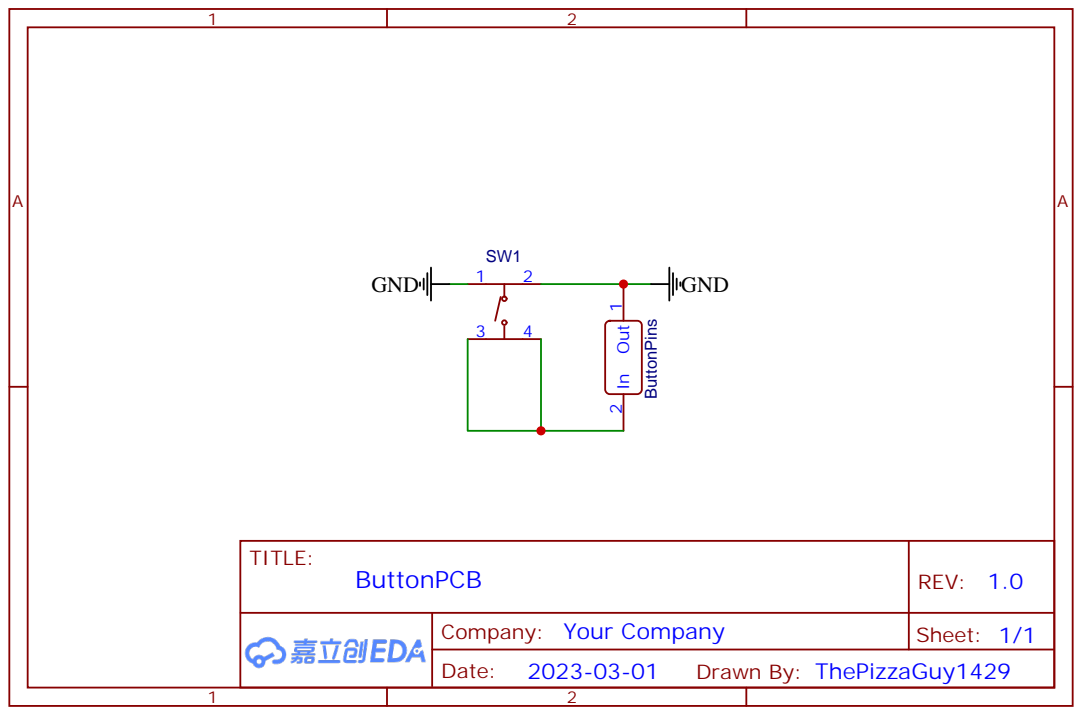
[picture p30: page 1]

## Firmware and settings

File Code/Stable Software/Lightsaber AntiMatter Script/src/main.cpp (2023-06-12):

#include <Arduino.h>

#include <Adafruit_NeoPixel.h>
#include <Adafruit_MPU6050.h>
#include <Adafruit_Sensor.h>
#include <SparkFun_PCA9536_Arduino_Library.h>
#include <Wire.h>
#include <Adafruit_MAX1704X.h>
#include <SparkFun_VL53L5CX_Library.h>
#include <SPI.h>
#include <SD.h>

#include <audio.h>
#include <bluetooth.h>

//Settings
#define testMode          false
#define audioEnabled      true
#define gyroEnabled       true
#define stabilityEnabled  true
#define strictStability   true

//Pin definitions
const int 
  ledPin = 32, ledLatch = 16, sysLatch = 4, chipSelect = 5, mosi = 23, 
  miso = 19, sck = 18, chargeStat = 13, usbDet = 33, button = 17;

//Constant variables
const int 
  resolution = 4 * 4, rangingFrequency = 60, sensorAddress[] = {0x45, 0x46, 0x47, 0x29}, stabilityRange = 50,
  numLeds = 223, brightness = 50, minBrightness = 0, maxBrightness = 150, 
  debounceTime = 50,
  incrementNum = 60, instantaneousWidth = 600, nominalWidth = 200, randomIncrement = 40;

const float 
  ledSpacing = 6.9444, heightOffset = 0.0,
  minVoltage = 3.3, maxVoltage = 4.2,
  maxVelocity = 3.0, 
  humNominalGain = 0.3, humMaxGain = 0.6;

#if !strictStability
  const unsigned int priorityMask[4][resolution] = 
  {
    {0, 0, 0, 0, 3, 2, 2, 3, 3, 1, 1, 3, 0, 0, 0, 0},
    {0, 0, 0, 0, 3, 2, 2, 3, 3, 1, 1, 3, 0, 0, 0, 0},
    {0, 0, 0, 0, 3, 2, 2, 3, 3, 1, 1, 3, 0, 0, 0, 0},
    {0, 0, 0, 0, 3, 1, 1, 3, 0, 0, 0, 0, 0, 0, 0, 0}
  }; //0 = don't use, 1 = primary, 2 = secondary, 3 = reserved (helper)
#else
  const unsigned int priorityMask[4][resolution] = 
  {
    {0, 0, 0, 0, 0, 0, 0, 0, 0, 1, 1, 0, 0, 0, 0, 0},
    {0, 0, 0, 0, 0, 0, 0, 0, 0, 1, 1, 0, 0, 0, 0, 0},
    {0, 0, 0, 0, 0, 0, 0, 0, 0, 1, 1, 0, 0, 0, 0, 0},
    {0, 0, 0, 0, 0, 1, 1, 0, 0, 0, 0, 0, 0, 0, 0, 0}
  }; //0 = don't use, 1 = primary
#endif

//Dynamic variables
unsigned long lastDebounceTime = 0;
int clashWidth[4], previousMeasurement[4], lastMeasurement[4];
float ledHeights[(numLeds-7)/2], minColVal[4];
int ledAnimationBrightness[(numLeds-7)/2];
float animationDisplacement = 0.0, animationVelocity = 0.1, animationAcceleration = 0.0;
bool audioOn = false, bluetoothOn = false, gyroscopeOn = false, vl53l5cxOn = false, isInContact = false, wasInContact = false;
int buttonState, lastButtonState = HIGH;
int previousPowerSetting;
String previousHumFile;

Adafruit_MPU6050 mpu;
Adafruit_MAX17048 lipo;
PCA9536 io;
Adafruit_NeoPixel strip = Adafruit_NeoPixel(numLeds, ledPin, NEO_GRB + NEO_KHZ800);

SparkFun_VL53L5CX sensor[4];
VL53L5CX_ResultsData MeasurementData[4];


void usbConnect() {

  digitalWrite(ledLatch, LOW);
  saveData(getColor(), getIRFile(), getIdleFile(), getShutdownOnDrop(), getPowerSetting());
  memShutdown();
  digitalWrite(sysLatch, LOW); 

  if(!bluetoothOn) {
    bluetoothInit();
    bluetoothOn = true;
  }

  while(!digitalRead(chargeStat)) {
    for (int i = 0; i < 255; i++) {
      strip.setPixelColor(0, map(i, 0, 255, 50, 128), 0, map(i, 0, 255, 50, 128));
      strip.show();
    }
    for (int i = 255; i > 0; i--) {
      strip.setPixelColor(0, map(i, 0, 255, 50, 128), 0, map(i, 0, 255, 50, 128));
      strip.show();
    }
    
    if (isDeviceConnected()) sendData(getIRFile() + "," + getIdleFile() + "," + getShutdownOnDrop() + "," + getPowerSetting() + "," + 0 + "," + "Charging");
  }

  strip.setPixelColor(0, 0, 255, 0);
  strip.show();
  while(true) {
    if(!isPlaying(0)) playWav("/ChargeDone.wav", 0, 0.1);
    audioLoop();
  }

}

void voltageTooLow() {
  digitalWrite(ledLatch, LOW);
  strip.setPixelColor(0, 255, 0, 0);
  strip.show();
  saveData(getColor(), getIRFile(), getIdleFile(), getShutdownOnDrop(), getPowerSetting());
  memShutdown();
  digitalWrite(sysLatch, LOW);
  while (true) {if(digitalRead(usbDet)) usbConnect();}
}

void ignition() {

  if (gyroEnabled) {
    if(!mpu.begin(0x69)) while(true);

    mpu.setAccelerometerRange(MPU6050_RANGE_16_G);
    mpu.setGyroRange(MPU6050_RANGE_250_DEG);
    mpu.setFilterBandwidth(MPU6050_BAND_21_HZ);
    gyroscopeOn = true;
  }

  playWav(("/" + getIRFile() + "Ignition.wav").c_str(), 0, 0.7);
  playWav(("/" + getIdleFile() + ".wav").c_str(), 1, humNominalGain);

  int lengthMs;
  if (getIRFile().equals("Alternative")) lengthMs = 1700;
  if (getIRFile().equals("Deep")) lengthMs = 1057;
  if (getIRFile().equals("Default")) lengthMs = 1495;
  if (getIRFile().equals("Quick")) lengthMs = 1583;
  if (getIRFile().equals("SemiDeep")) lengthMs = 1051;
  int delayTime;
  if(lengthMs > 1100) {
    delayTime = lengthMs/((numLeds-7)/4);
  } else {
    delayTime = lengthMs/((numLeds-7)/4);
  }

  //for(int i = 1; i < 7; i++) strip.setPixelColor(i, getColor());
  //strip.show();

  uint32_t virtualLedStrip[(numLeds-7)/2];

  for(int i = 0; i < (numLeds-7)/2; i++) {

    long currTime = millis();

    animationVelocity += animationAcceleration;
    animationDisplacement += animationVelocity;
    animationDisplacement = fmod(animationDisplacement, 2.0);

    for(int j = 0; j < (numLeds-7)/2; j++) virtualLedStrip[j] = 0x00;
    i++;
    if(lengthMs < 1100) i++;
    for(int j = 0; j < i; j++) virtualLedStrip[j] = getColor();
    for(int j = 0; j < (numLeds-7)/2; j++) {
      ledAnimationBrightness[j] = getBumpBrightness(ledHeights[j], 1.0, 255.0, animationDisplacement, 0.0005, -0.3, 255.0, -1.0);
      virtualLedStrip[j] = bumpPixelBrightness(virtualLedStrip[j], ledAnimationBrightness[j]);
    }

    for(int j = 1; j < 7; j++) strip.setPixelColor(j, virtualLedStrip[0]);

    for(int j = 0; j < (numLeds-7)/2; j++) {
      strip.setPixelColor(j+7, virtualLedStrip[j]);
      strip.setPixelColor(numLeds-j-1, virtualLedStrip[j]);
    }

    strip.show();

    bluetoothLoop();

    if(digitalRead(usbDet) && !testMode) usbConnect();
    if (lipo.cellVoltage() < minVoltage) voltageTooLow();
    float batteryPercent = mapFloat(lipo.cellVoltage(), minVoltage, maxVoltage, 0.0, 100.0);
    strip.setPixelColor(0, map(batteryPercent, 0.0, 100.0, 255, 0), map(batteryPercent, 0.0, 100.0, 0, 255), 0);

    if (isDeviceConnected()) sendData(getIRFile() + "," + getIdleFile() + "," + getShutdownOnDrop() + "," + getPowerSetting() + "," + batteryPercent + "," + "Running");

    int targetDelay = delayTime-millis()+currTime-1;
    long currentTimeStamp = millis();
    while(millis()-currentTimeStamp < targetDelay) audioLoop();

  }

}

void retraction() { 

  playWav(("/" + getIRFile() + "Retraction.wav").c_str(), 0, 0.7);

  int lengthMs;
  if (getIRFile().equals("Alternative")) lengthMs = 1700;
  if (getIRFile().equals("Deep")) lengthMs = 1057;
  if (getIRFile().equals("Default")) lengthMs = 1495;
  if (getIRFile().equals("Quick")) lengthMs = 1583;
  if (getIRFile().equals("SemiDeep")) lengthMs = 1051;
  int delayTime;
  if(lengthMs > 1100) {
    delayTime = lengthMs/((numLeds-7)/4);
  } else {
    delayTime = lengthMs/((numLeds-7)/4);
  }

  stopWav(1);

  uint32_t virtualLedStrip[(numLeds-7)/2];

  for(int i = ((numLeds-7)/2)-1; i >= 0; i--) {

    long currTime = millis();

    animationVelocity += animationAcceleration;
    animationDisplacement += animationVelocity;
    animationDisplacement = fmod(animationDisplacement, 2.0);

    for(int j = 0; j < (numLeds-7)/2; j++) virtualLedStrip[j] = getColor();
    i--;
    if(lengthMs < 1100) i--;
    for(int j = i; j < (numLeds-7)/2; j++) virtualLedStrip[j] = 0x00;
    for(int j = 0; j < (numLeds-7)/2; j++) {
      ledAnimationBrightness[j] = getBumpBrightness(ledHeights[j], 1.0, 255.0, animationDisplacement, 0.0005, -0.3, 255.0, -1.0);
      virtualLedStrip[j] = bumpPixelBrightness(virtualLedStrip[j], ledAnimationBrightness[j]);
    }

    for(int j = 1; j < 7; j++) strip.setPixelColor(j, virtualLedStrip[0]);

    for(int j = 0; j < (numLeds-7)/2; j++) {
      strip.setPixelColor(j+7, virtualLedStrip[j]);
      strip.setPixelColor(numLeds-j-1, virtualLedStrip[j]);
    }

    strip.show();

    bluetoothLoop();

    if(digitalRead(usbDet) && !testMode) usbConnect();
    if (lipo.cellVoltage() < minVoltage) voltageTooLow();
    float batteryPercent = mapFloat(lipo.cellVoltage(), minVoltage, maxVoltage, 0.0, 100.0);
    strip.setPixelColor(0, map(batteryPercent, 0.0, 100.0, 255, 0), map(batteryPercent, 0.0, 100.0, 0, 255), 0);

    if (isDeviceConnected()) sendData(getIRFile() + "," + getIdleFile() + "," + getShutdownOnDrop() + "," + getPowerSetting() + "," + batteryPercent + "," + "Running");

    int targetDelay = delayTime-millis()+currTime-1;
    long currentTimeStamp = millis();
    while(millis()-currentTimeStamp < targetDelay) audioLoop();

  }

  for(int i = 6; i >= 1; i--) strip.setPixelColor(i, 0, 0, 0);
  strip.show();

}

void sensorSetup() {

  for (int i = 0; i < 4; i++) io.pinMode(i, OUTPUT);
  for (int i = 0; i < 4; i++) io.digitalWrite(i, LOW);

  for(int i = 1; i < numLeds; i++) strip.setPixelColor(i, 0, 0, 0);
  strip.setPixelColor(1, getColor());
  strip.show();

  Serial.println("Starting sensors ");
  Serial.println("[        ] 0%");

  bool individualVL53L5CXOn[4] = {false, false, false, false};
  vl53l5cxOn = false;
  for(int i = 0; i < 4; i++) {
    if (!vl53l5cxOn) {
      io.digitalWrite(i, HIGH);
      if(!sensor[i].begin()) {
        Serial.print("Sensor ");
        Serial.print(i);
        Serial.println(" failed");
      } else {
        sensor[i].setAddress(sensorAddress[i]);
        sensor[i].setResolution(resolution);
        sensor[i].setRangingMode(SF_VL53L5CX_RANGING_MODE::CONTINUOUS);
        sensor[i].setRangingFrequency(rangingFrequency);
        sensor[i].startRanging();
        individualVL53L5CXOn[i] = true;
      }
    }
    if (i == 0) Serial.println("[==      ] 25%  ");
    if (i == 1) Serial.println("[====    ] 50%  ");
    if (i == 2) Serial.println("[======  ] 75%  ");
    if (i == 3) Serial.println("[========] 100% ");
  }
  vl53l5cxOn = true;
  for(int i = 0; i < 4; i++) if(!individualVL53L5CXOn[i]) vl53l5cxOn = false;
  Serial.println("VL53L5CX sensors started");

}



void setup() {

  pinMode(sysLatch, OUTPUT);
  digitalWrite(sysLatch, HIGH);

  Serial.begin(115200);
  Wire.begin();
  Wire.setClock(1000000);

  io.begin();
  pinMode(usbDet, INPUT);
  pinMode(chargeStat, INPUT_PULLUP);
  pinMode(button, INPUT_PULLUP);

  lipo.begin();

  memInitData();

  for(int i = 0; i < (numLeds-7)/2; i++) {
    ledHeights[i] = ((float)i*ledSpacing)+heightOffset;
    ledAnimationBrightness[i] = 0;
  }
  for(int i = 0; i < 4; i++) {
    previousMeasurement[i] = -1 * stabilityRange;
    lastMeasurement[i] = -1 * stabilityRange;
    minColVal[i] = 0.1;
  }
  previousHumFile = getIdleFile();
  previousPowerSetting = getPowerSetting();

  audioInit();

  strip.begin();
  strip.setBrightness(map(getPowerSetting(), 0, 255, minBrightness, maxBrightness));
  strip.show();

  if (digitalRead(usbDet) && !testMode) usbConnect(); 

  while(lipo.cellVoltage() == 0.00);
  if (lipo.cellVoltage() < minVoltage) voltageTooLow();
  float batteryPercent = mapFloat(lipo.cellVoltage(), minVoltage, maxVoltage, 0.0, 100.0);
  strip.setPixelColor(0, map(batteryPercent, 0.0, 100.0, 255, 0), map(batteryPercent, 0.0, 100.0, 0, 255), 0);
  strip.show();

  bluetoothInit();
  bluetoothOn = true;

  pinMode(ledLatch, OUTPUT);
  digitalWrite(ledLatch, HIGH);

  SPI.begin(sck, miso, mosi);
  SD.begin(chipSelect);

  sensorSetup();

  ignition();

}

void loop() {

  exitSleep:

  if (digitalRead(usbDet) && !testMode) usbConnect();

  if (lipo.cellVoltage() < minVoltage) voltageTooLow();
  float batteryPercent = mapFloat(lipo.cellVoltage(), minVoltage, maxVoltage, 0.0, 100.0);
  strip.setPixelColor(0, map(batteryPercent, 0.0, 100.0, 255, 0), map(batteryPercent, 0.0, 100.0, 0, 255), 0);

  for(int i=1; i<numLeds; i++) strip.setPixelColor(i, getColor());

  if(vl53l5cxOn) for(int i = 0; i < 4; i++) if(sensor[i].isDataReady()) sensor[i].getRangingData(&MeasurementData[i]);

  if (gyroEnabled) {
    sensors_event_t a, g, temp;
    mpu.getEvent(&a, &g, &temp);

    float currentVelocity = calculateMagnitudeVelocity(g.gyro.x, g.gyro.y, g.gyro.z);
    float currentHumGain = mapFloat(currentVelocity, 0.0, maxVelocity, humNominalGain, humMaxGain);
    setGain(1, currentHumGain);

    animationVelocity = mapFloat(currentVelocity, 0.0, maxVelocity, 0.1, 0.2);
  }

  //Height processing
  int currentMeasurement[4] = {-1 * stabilityRange, -1 * stabilityRange, -1 * stabilityRange, -1 * stabilityRange};
  for (int i = 0; i < 4; i++ ) {
    int priority = 1;
    while(priority < 3) {
      for(int j = 0; j < resolution; j++) {
        if(priorityMask[i][j] == priority && MeasurementData[i].target_status[j] == 5) {
          currentMeasurement[i] = MeasurementData[i].distance_mm[j];
          goto foundMeasurement;
        }
      }
      priority++;
    }
    foundMeasurement:
    ;
  }

  for(int i = 0; i < 4; i++) {
    if(currentMeasurement[i] > 760) currentMeasurement[i] = -1 * stabilityRange;
  }

  bool currentMeasurementStable[4] = {false, false, false, false};
  for(int i = 0; i < 4; i++) if(abs(currentMeasurement[i] - previousMeasurement[i]) < stabilityRange) currentMeasurementStable[i] = true;
  if (!stabilityEnabled) for (int i = 0; i < 4; i++) currentMeasurementStable[i] = true;

  int sensorMeasurement[4] = {-1, -1, -1, -1};
  for(int i = 0; i < 4; i++) if (currentMeasurement[i] > 0 && currentMeasurementStable[i]) sensorMeasurement[i] = currentMeasurement[i];

  for(int i = 0; i < 4; i++) if((currentMeasurement[i] < 0 || !currentMeasurementStable[i]) && previousMeasurement[i] > 0) lastMeasurement[i] = previousMeasurement[i];

  audioLoop();

  for(int i = 0; i < 4; i++) {
    minColVal[i] = 1.0;
    if(currentMeasurement[i] > 0 && currentMeasurementStable[i] && clashWidth[i] == 0) clashWidth[i] = instantaneousWidth;
    if(currentMeasurement[i] > 0 && currentMeasurementStable[i] && clashWidth[i] > nominalWidth) clashWidth[i]-=incrementNum;
    if(currentMeasurement[i] > 0 && currentMeasurementStable[i] && clashWidth[i] < nominalWidth) clashWidth[i]+=incrementNum;
    if((currentMeasurement[i] < 0 || !currentMeasurementStable[i]) && clashWidth[i] > 0) clashWidth[i]-=incrementNum;
    if(clashWidth[i] < 0) clashWidth[i] = 0;
    if(currentMeasurement[i] > 0 && currentMeasurementStable[i] && clashWidth[i] > 0) {
      bool sign = random(0, 2);
      if(sign) {
        clashWidth[i] += randomIncrement;
      } else {
        clashWidth[i] -= randomIncrement;
      }
      if(clashWidth[i] < 0) clashWidth[i] = 0;
    }
    minColVal[i] = mapFloat(clashWidth[i], 0.0, nominalWidth, 1.0, 0.1);
    if(minColVal[i] > 1.0) minColVal[i] = 1.0;
    if(minColVal[i] < 0.1) minColVal[i] = 0.1;
  }

  //==================================================================================================================================//
  //CHECK THIS
  animationVelocity += animationAcceleration;
  animationDisplacement += animationVelocity;
  animationDisplacement = fmod(animationDisplacement, 2.0);

  for(int i = 0; i < (numLeds-7)/2; i++) ledAnimationBrightness[i] = getBumpBrightness(ledHeights[i], 1.0, 255.0, animationDisplacement, 0.0005, -0.3, 255.0, -1.0); //CHECK THESE VALUES

  uint32_t virtualLedStrip[4][(numLeds-7)/2];
  for(int i = 0; i < 4; i++) for(int j = 0; j < (numLeds-7)/2; j++) virtualLedStrip[i][j] = bumpPixelBrightness(getColor(), ledAnimationBrightness[j]);

  for(int i = 1; i < 7; i++) strip.setPixelColor(i, virtualLedStrip[0][0]);
  //==================================================================================================================================//

  for(int i = 0; i < 4; i++) {
    if(currentMeasurement[i] > 0 && currentMeasurementStable[i]) {
      for(int j = 0; j < (numLeds-7)/2; j++) virtualLedStrip[i][j] = calculateColor(ledHeights[j], 170, currentMeasurement[i], clashWidth[i], virtualLedStrip[i][j], minColVal[i]);
    } else {
      if(lastMeasurement[i] > 0) for(int j = 0; j < (numLeds-7)/2; j++) virtualLedStrip[i][j] = calculateColor(ledHeights[j], 170, lastMeasurement[i], clashWidth[i], virtualLedStrip[i][j], minColVal[i]);
    }
  }

  uint32_t finalVirtualLedStrip[(numLeds-7)/2];
  for(int i = 0; i < (numLeds-7)/2; i++) finalVirtualLedStrip[i] = calculatePixel(virtualLedStrip[0][i], virtualLedStrip[1][i], virtualLedStrip[2][i], virtualLedStrip[3][i]);
  for(int i = 0; i < 4; i++) previousMeasurement[i] = currentMeasurement[i];

  for(int i = 0; i < (numLeds-7)/2; i++) {
    strip.setPixelColor(i+7, finalVirtualLedStrip[i]);
    strip.setPixelColor(numLeds-i-1, finalVirtualLedStrip[i]);
  }

  if (isDeviceConnected()) sendData(getIRFile() + "," + getIdleFile() + "," + getShutdownOnDrop() + "," + getPowerSetting() + "," + batteryPercent + "," + "Running");

  bluetoothLoop();

  audioLoop();
 
  if (!isPlaying(1)) playWav(("/" + getIdleFile() + ".wav").c_str(), 1, humNominalGain);

  String currentHumFile = getIdleFile();
  if(!currentHumFile.equals(previousHumFile)) playWav(("/" + currentHumFile + ".wav").c_str(), 1, humNominalGain);
  previousHumFile = currentHumFile;

  //CHECK THIS
  int currentPowerSetting = getPowerSetting();
  if(currentPowerSetting != previousPowerSetting) {
    strip.setBrightness(map(currentPowerSetting, 0, 255, minBrightness, maxBrightness));
  }
  previousPowerSetting = currentPowerSetting;

  //Sound
  isInContact = false;
  for(int i = 0; i < 4; i++) {
    if(currentMeasurement[i] > 0 && currentMeasurementStable[i])
    isInContact = true;
  }

  const float clashGainSelection = 0.7;
  if (isInContact && !wasInContact) { 
    if (!isPlaying(0)) {
      if (random(0, 2)) {
        playWav("/ClashFinalLong1.wav", 0, clashGainSelection);
      } else {
        playWav("/ClashFinalLong2.wav", 0, clashGainSelection);
      }
    } else {
      stopFade();
      fadeTo(0, 50, clashGainSelection);
    }
  }
  
  if(!isInContact && wasInContact) {
    stopFade();
    fadeTo(0, 200, 0.0);
  }

  audioLoop();

  wasInContact = isInContact;

  //Check button and touch
  bool isReleased = false;
  int reading = digitalRead(button);
  
  if(reading != lastButtonState) lastDebounceTime = millis();
  
  if(millis()-lastDebounceTime > debounceTime) {
    if(reading != buttonState) {
      buttonState = reading;
  
      if(buttonState == LOW) isReleased = true;
    }
  }
  lastButtonState = reading;

  if(isReleased || (touchRead(6) < 100 && getShutdownOnDrop() && false)) {

    retraction();
    digitalWrite(ledLatch, LOW);
    long currentTime = millis();

    while (millis() - currentTime < 300000) {

      if (digitalRead(usbDet) && !testMode) usbConnect();

      if (lipo.cellVoltage() < minVoltage) voltageTooLow();
      float batteryPercent = mapFloat(lipo.cellVoltage(), minVoltage, maxVoltage, 0.0, 100.0);
      strip.setPixelColor(0, map(batteryPercent, 0.0, 100.0, 255, 0), map(batteryPercent, 0.0, 100.0, 0, 255), 0);
      strip.show();

      //Check button
      isReleased = false;
      reading = digitalRead(button);
      
      if(reading != lastButtonState) lastDebounceTime = millis();
      
      if(millis()-lastDebounceTime > debounceTime) {
        if(reading != buttonState) {
          buttonState = reading;
      
          if(buttonState == LOW) isReleased = true;
        }
      }
      lastButtonState = reading;

      if(isReleased || (touchRead(6) > 100 && getShutdownOnDrop() && false)) {
        digitalWrite(ledLatch, HIGH);
        ignition();
        goto exitSleep;
      }

      if (isDeviceConnected()) sendData(getIRFile() + "," + getIdleFile() + "," + getShutdownOnDrop() + "," + getPowerSetting() + "," + 0 + "," + "Resting");

    }

    saveData(getColor(), getIRFile(), getIdleFile(), getShutdownOnDrop(), getPowerSetting());
    memShutdown();
    digitalWrite(sysLatch, LOW);

  }

  strip.show();

  audioLoop();

}

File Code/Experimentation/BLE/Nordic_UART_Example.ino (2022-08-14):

 /*Created by Muhammad Hammad on 21st October, 2021,
 * Email: muhammad.hammad1201@gmail.com
 * iOs App Source Code tested with this example: https://github.com/hammad1201/BLESerialIOsExample
 */
 
#include <BLEDevice.h>
#include <BLEServer.h>
#include <BLEUtils.h>
#include <BLE2902.h>

BLEServer *pServer = NULL;
BLECharacteristic * pTxCharacteristic;
bool deviceConnected = false;
bool oldDeviceConnected = false;
bool reconnected = false;

String buff;
bool serialAvailable = false;

#define SERVICE_UUID           "6e400001-b5a3-f393-e0a9-e50e24dcca9e" // UART service UUID
#define CHARACTERISTIC_UUID_RX "6e400002-b5a3-f393-e0a9-e50e24dcca9e"
#define CHARACTERISTIC_UUID_TX "6e400003-b5a3-f393-e0a9-e50e24dcca9e"

void handleBLEAdvertisement(void);

class MyServerCallbacks: public BLEServerCallbacks {
    void onConnect(BLEServer* pServer) {
      Serial.println("Connected!");
      deviceConnected = true;  
    };

    void onDisconnect(BLEServer* pServer) {
      Serial.println("Disconnected!");
      deviceConnected = false;
      serialAvailable = false;
    }
};

class MyCallbacks: public BLECharacteristicCallbacks {
    void onWrite(BLECharacteristic *pCharacteristic) {
      std::string rxValue = pCharacteristic->getValue();
      
      if (rxValue.length() > 0) {
        Serial.println("*********");
        Serial.print("Received Value: ");
        for (int i = 0; i < rxValue.length(); i++)
          Serial.print(rxValue[i]);

        Serial.println();
        Serial.println("*********");
      }
    }
};  


void setup() {
  Serial.begin(115200);

  // Create the BLE Device
  BLEDevice::init("Lightsaber [Anti-matter]"); //Nordic UART Service

  // Create the BLE Server
  pServer = BLEDevice::createServer();
  pServer->setCallbacks(new MyServerCallbacks());

  // Create the BLE Service
  BLEService *pService = pServer->createService(SERVICE_UUID);

  // Create a BLE Characteristic
  pTxCharacteristic = pService->createCharacteristic(
                        CHARACTERISTIC_UUID_TX,
                        BLECharacteristic::PROPERTY_NOTIFY
                      );

  pTxCharacteristic->addDescriptor(new BLE2902());

  BLECharacteristic * pRxCharacteristic = pService->createCharacteristic(
      CHARACTERISTIC_UUID_RX,
      BLECharacteristic::PROPERTY_WRITE
                                          );

  pRxCharacteristic->setCallbacks(new MyCallbacks());

  // Start the service
  pService->start();

  // Start advertising
  pServer->getAdvertising()->start();
  Serial.println("Waiting a client connection to notify...");
}

void loop() {
  if (deviceConnected) {

    if (Serial.available()) {
      buff = Serial.readString();
      serialAvailable = true;
    }

    if (serialAvailable == true) {
      Serial.print(buff);
      pTxCharacteristic->setValue(buff.c_str());
      pTxCharacteristic->notify();
      serialAvailable = false;
      buff = ""; //Clear the string
    }
  }

  handleBLEAdvertisement();
}

void handleBLEAdvertisement() {
  if (!deviceConnected && oldDeviceConnected) {
    delay(500);
    pServer->startAdvertising();
    Serial.println("Start Advertising Again!");
    oldDeviceConnected = deviceConnected;
  }
  if (deviceConnected && !oldDeviceConnected) {
    oldDeviceConnected = deviceConnected;
  }
}
